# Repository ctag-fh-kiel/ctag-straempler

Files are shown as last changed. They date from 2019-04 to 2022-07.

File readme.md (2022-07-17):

# **CTAG Strämpler**
This repository contains the firmware and the hardwaredesigns (CTAG and [Antumbra](http://www.antumbra.eu/)) of Strämpler.

!!**NEW**!! Strämpler firmware can now be built in the cloud using Github actions
!!**NEW**!! Strämpler can now run [CTAG TBD](https://github.com/ctag-fh-kiel/ctag-tbd) as alternative firmware! Enclosed in /bin folder!

Strämpler harware UI

## What it is:
- Half streamer, half sampler, therefore called Strämpler (close to German word of Strampler meaning romper suit).
- Allows streaming of large audio files from SD card (limit 2GB file size due to FAT32 used).
- A eurorack modular synth module with 22 HP width and an internet connection.
- A bridge to connect to [freesound.org](https://freesound.org), to play with samples within your modular synth setup.
- Allows tweaking of your sound just like you'd do with a sampler + *a modular synth*.
- Allows to parameter tweak and modulate sounds by control voltage (CV), employing a complex modulation matrix.

## Why it is:
- A group of audio enthusiasts enjoying coding and hardware making.
- The sexiness of sampling for sound design and synthesis.
- The (subjective) need to have more sampling modules in the eurorack modular synth domain.
- The (subjective) need to make eurorack more compatible with internet of things.
- Build a platform to learn, build and practise skills, and engage students.
- To allow anyone to understand technology by offering open access.
- To benchmark the capabilities of the WiFi/BLE enabled [Espressif ESP32](https://docs.espressif.com/projects/esp-idf/en/latest/#) platform and get a deep understanding of it.
- To squeeze and optimize code so that it can work on a small embedded system.
- Because we can.
- Because of some inspiration of the [Elektron Octatrack](https://www.elektron.se/products/octatrack-mkii/).

## Features: 
- 2 voice eurorack sample streaming module.
- Streaming of large sound files from SD-card (limited by FAT32 2GB).
- Internet connection to [freesound.org](https://freesound.org), allows to download files through freesound.org api onto SD-card of module.
- One ADSR per voice to control sample amplitude.
- One band pass filter per voice with controllable base, width and Q. Can be used as low / high pass (biquad implmentation).
- Arbitrary playback speed adjustment (+/- 100%). 
- Pitching +/- 12 halftones, samples can be played e.g. using external gate / CV keyboard.
- Distortion per voice (tanh() saturation).
- Delay as send effect (stereo, ping pong, max delay time 1.5s).
- External stereo input, with delay send, mix with voices.
- Modulation matrix, where many parameters can be modulated using external CV.
- Gate and latch modes for sample playback.
- REST-API for user file upload (service discovery by MDNS / bonjour).
- 44.1kHz, 32 bit float internal resolution, 24 bit codec resolution, 12 bit CV input resolution sampled at 2KHz (yes, modulation in the audio range is possible to a certain extend), approx. 1ms DSP buffer latency  (32 words per channel).
- Approx. 100mA +12V / 10mA -12V power draw.

## Potential new features / current limitations / work to be done:
- Sampling of external input. 
- Upload to freesound.org.
- Improved sound browser, browse by tag, browse by search.
- More testing of modulation.
- More effects.
- More performance optimization.
- Automatic voice alternation.
- Bug identification and fixing.
- Code refactoring to make things more beautiful.
- More user friendly interaction.
- Documentation / tutorials.
- Your ideas?

## How to engage yourself:
- Join the [enthusiastic developer](https://codewithoutrules.com/2018/11/12/enthusiasts-vs-pragmatists/) team on Github.
- Help build and spread the hardware module (and the word).
- Use Strämpler to create cool sounds and music and share them (with a link to us).
- More ideas?

## Words of caution: 
- CTAG Strämpler does contain bugs, it comes without warranty of any kind, none of the authors are liable to damages arising by the use of it.
- CTAG Strämpler is an intermediate to advanced project, both in terms of hardware and software design:
    - In order to build the hardware you need intermediate to advanced SMD soldering skills and respective tools. I.e. the PCB contains many 0604 SMD components as well as TSSOP packages and a QFN. However, with a bit of practise you will be able to DIY build your own module. Dare and be rewarded, tackle the frustration on the path, it's worth it. The idea of the platform is also to boost your soldering skills, it *CAN* all be done by hand.
    - The software is built using [Espressif IDF](https://esp-idf.readthedocs.io) using the C programming language. Intermediate knowledge of C is required to understand the code. Furthermore, some basic DSP algorithms are applied. A DSP newbie, however, could take the project to really get rolling and build up on DSP capabilities. CTAG Strämpler is ideal to try out and play with your own DSP algorithms.
- The [Espressif ESP32](https://en.wikipedia.org/wiki/ESP32) platform used for CTAG Strämpler is, with regard to its computational power and I/O capabilities, hard at its limit. We're squeezing the platform here and are already surprised, what one can get out of $5 chip in the year 2019. Surely, other DSPs / microcontrollers could do a better job, but do they allow for internet of things as easily?

## How to get started / user manual:
See the [Wiki pages](https://github.com/ctag-fh-kiel/ctag-straempler/wiki) of this project.

## Build instructions
The easiest way is to create a fork on Github from this repository. Then make sure GitHub Actions are activated for your fork by going to the corresponding tab at your fork and clicking on the green button.
Every time you push new commits into your fork (master or dev branch) the action will build a new draft release, which will upon successful run of the action be available at your fork's release tab.

If you want to build on your own system, you can use a virtual development environment image with Docker (see here for [ESP IDF Docker instructions](https://docs.espressif.com/projects/esp-idf/en/latest/esp32/api-guides/tools/idf-docker-image.html)). 
Here are some steps:
- Install [Docker](https://www.docker.com/)
- Install [Git](https://git-scm.com/)
- Open a command line shell
- Clone the Strämpler repository and submodules with ```git clone --recurse-submodules https://github.com/ctag-fh-kiel/ctag-straempler.git``` and change into it with ```cd ctag-straempler```
- Build the firmware with ```docker run --rm -v $PWD:/project -w /project rma31/idf:v4.1-strampler idf.py build```

You can edit the source files using any IDE / text editor you like.
## Flash instructions
- Either download the firmware from the Github release tab or use your own
- Install [ESP Tool](https://github.com/espressif/esptool)
- Adapt the [Firmware flash script](https://github.com/ctag-fh-kiel/ctag-straempler/blob/master/bin/flash.sh) to your system needs and flash the firmware

## Hardware
All hardware design can be found [https://github.com/ctag-fh-kiel/esp32-eurorack-audio](https://github.com/ctag-fh-kiel/esp32-eurorack-audio).

## Links
- [Demonstration videos on YouTube](https://youtu.be/zmj8tKPHV8g).

## Licenses:
- Hardware is licensed under [Creative Commons Attribution-NonCommercial-ShareAlike 4.0 International (CC BY-NC-SA 4.0)](https://creativecommons.org/licenses/by-nc-sa/4.0/).
- Software licenses, see [license](LICENSE) file.
- Freesound license: [Freesound.org API terms](https://freesound.org/docs/api/terms_of_use.html) and [here](https://freesound.org/help/tos_api/) as well as the [freesound website terms of use](https://freesound.org/help/tos_web/).
- Don't forget to obey the license of the respective sound files used in your music. License details are shown for the individual sound file in your CTAG Strämpler sound browser, including the sound file authors name.

## Who made this happen:
- The team of [CTAG (Creative Technologies Arbeitsgruppe) at Kiel University of Applied Science](https://www.creative-technologies.de), including:
    - Robert Manzke
    - Phillip Lamp
    - Niklas Wantrupp
    - With kind support for the front panel design by David Knop from [instruments of things](http://www.instrumentsofthings.com/).
- [Antumbra](http://www.antumbra.eu/)
- More people like you :)

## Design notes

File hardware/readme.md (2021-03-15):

# Hardware
This directory contains two alternative hardware designs, the original CTAG and a beautiful smaller form factor redesign by [Antumbra](http://www.antumbra.eu/).
Apply a "git submodule update --init --recursive".

## CTAG 
Designs are in KiCad Format. Original hardware repo added through git submodule.

## Antumbra
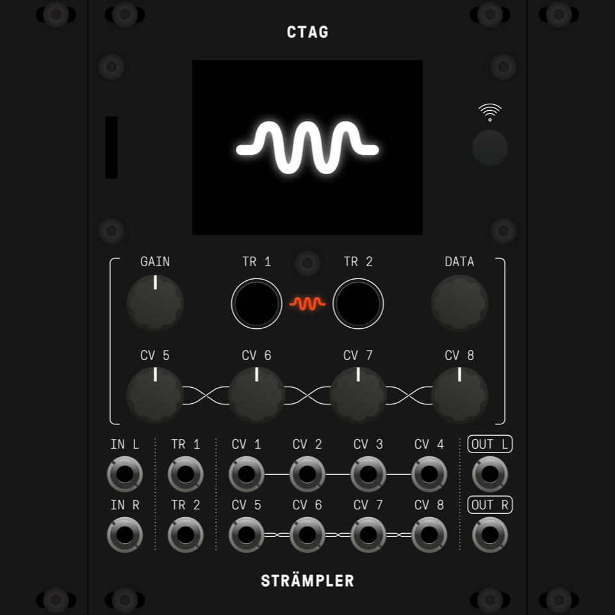
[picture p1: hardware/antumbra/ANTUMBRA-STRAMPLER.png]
Antumbra UI

Designs are in Eagle Cad Format.

[BOM](https://docs.google.com/spreadsheets/d/16I0Fnxrp7fq1aB0nhNF5OuEwzjhC1HZl9R4_WuAPDM4)

[Mouser cart](https://www.mouser.com/ProjectManager/ProjectDetail.aspx?AccessID=9c1a090daf)

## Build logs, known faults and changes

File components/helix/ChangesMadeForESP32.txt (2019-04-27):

The following changes have been made to the Helix MP3 decoder source code
for porting on to the ESP32 microcontroller. 

- Modified CNZ to use GCC default
- Modified MULSHIFT32 to not use assembler code

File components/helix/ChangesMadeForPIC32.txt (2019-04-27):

The following changes have been made to the Helix MP3 decoder source code
for porting on to the PIC32MX microcontroller. 

1. Commented out the assembly implementation of FASTABS() function in
assembly.h and replaced with the C equivalent.

2. Commented out the line 47 in file mp3dec.h as this may not be 
applicable to the PIC32.

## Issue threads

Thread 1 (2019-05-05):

Sample start, loop start/stop positions need update when sound changed

ctag-fh-kiel, 2019-05-05:
Sample start, loop start/stop positions seem to remain calculated for the previous sample, if new sample is loaded. They are set correctly once one edits the value in the playmodes menu.
Needs fix that values are set correctly upon new sound to slot assignment.

Closed 2019-05-06.

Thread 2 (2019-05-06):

Unable to build

morganrallen, 2019-05-06:
Hi all! I'm currently working on a ESP32 based synth project and looking for inspiration as this is quite foreign territory for me. While I'm comfortable with `ESP-IDF`, I feel like something might be missing.

I've ensure I have the latest xtensa tools, IDF is up to date (including submodules, python) but am met with this compilation error.

```
/home/morgan/devel/ctag-straempler/components/audio/audio.c:76:32: error: missing braces around initializer [-Werror=missing-braces]
 atomic_bool trigModeLatch[2] = {false, false};
                                ^
/home/morgan/devel/ctag-straempler/components/audio/audio.c:76:32: note: (near initialization for 'trigModeLatch')
/home/morgan/devel/ctag-straempler/components/audio/audio.c: In function 'enableTrigModeLatch':
/home/morgan/devel/ctag-straempler/components/audio/audio.c:945:24: error: incompatible types when assigning to type 'atomic_bool {aka struct <anonymous>}' from type 'int'
     trigModeLatch[vid] = true;
                        ^
/home/morgan/devel/ctag-straempler/components/audio/audio.c: In function 'disableTrigModeLatch':
/home/morgan/devel/ctag-straempler/components/audio/audio.c:949:24: error: incompatible types when assigning to type 'atomic_bool {aka struct <anonymous>}' from type 'int'
     trigModeLatch[vid] = false;
                        ^
/home/morgan/devel/ctag-straempler/components/audio/audio.c: In function 'audio_task':
/home/morgan/devel/ctag-straempler/components/audio/audio.c:1033:20: error: used struct type value where scalar is required
                 if(trigModeLatch[vid]){
                    ^
/home/morgan/devel/ctag-straempler/components/audio/audio.c: In function 'assignAudioFiles':
/home/morgan/devel/ctag-straempler/components/audio/audio.c:1179:43: error: 'FIL {aka struct <anonymous>}' has no member named 'cltbl'
                         audio_files[i].fil.cltbl = audio_files[i].clmt;
                                           ^
/home/morgan/devel/ctag-straempler/components/audio/audio.c:1180:43: error: 'FIL {aka struct <anonymous>}' has no member named 'cltbl'
                         audio_files[i].fil.cltbl[0] = SZ_TBL;
                                           ^
/home/morgan/devel/ctag-straempler/components/audio/audio.c: At top level:
cc1: warning: unrecognized command line option '-Wno-int-in-bool-context'
cc1: warning: unrecognized command line option '-Wno-memset-elt-size'
cc1: warning: unrecognized command line option '-Wno-format-truncation'
cc1: warning: unrecognized command line option '-Wno-switch-unreachable'
cc1: warning: unrecognized command line option '-Wno-unused-const-variable'
cc1: warning: unrecognized command line option '-Wno-implicit-fallthrough'
cc1: warning: unrecognized command line option '-Wno-cast-function-type'
cc1: warning: unrecognized command line option '-Wno-misleading-indentation'
cc1: warning: unrecognized command line option '-Wno-stringop-truncation'
cc1: warning: unrecognized command line option '-Wno-format-overflow'
cc1: warning: unrecognized command line option '-Wno-frame-address'
```

Trying to hack through these just leads to more and one warning of note...
```
/home/morgan/devel/ESP32/esp-idf/components/esp32/include/rom/lldesc.h:1:2: warning: #warning rom/lldesc.h is deprecated, please use esp32/rom/lldesc.h instead [-Wcpp]
```

This makes me think you're possibly using an old checkout of IDF?

ctag-fh-kiel, 2019-05-06:
Hi morganrallen,

In order to build the project, you need the newest compiler GCC 8.2, see this post https://esp32.com/viewtopic.php?t=7400

Also, we use a modified ESP-IDF due to issues with the fatfs implementation.

Please check out the wiki here as well, on how to build the project:
https://github.com/ctag-fh-kiel/ctag-straempler/wiki/GettingStarted

Do let us know if you still have problems ;)

ctag-fh-kiel, 2019-05-07:
Closing this issue...

morganrallen, 2019-05-07:
Ah crap! I overlooked the wiki. I will give that a try when I've got free time again. Maybe call out build instruction on the readme?

ctag-fh-kiel, 2019-05-08:
Updated the readme, thanks for the advice...

Closed 2019-05-07.

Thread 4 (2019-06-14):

Playback partially corrupted when start + PBspeed modulated

ctag-fh-kiel, 2019-06-14:
Seems as if playback goes beyond sample limit, resulting in noise and partially crashes...
Seems to happen only in single shot mode.

ctag-fh-kiel, 2019-06-14:
Appears fixed in d439aac...

Closed 2019-06-14.

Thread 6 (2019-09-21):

Setting up toolchain as per instructions - failed ! (My fault but struggling)

forestcaver, 2019-09-21:
I’m really struggling to build the firmware.
I’ve followed the instructions to the letter
I have unpacked the binary download of gcc 8.2

I am really unsure whether and how to replace the xtensa / esp-idf toolchain
I’ve tried changing my path to the gcc 8.2 and setting the prefix in the menuconfig
But I’m really struggling to setup the paths to gcc 8.2
I cant find anything useful on the esp forums.

I appreciate it’s not really an issue with the code but dont know how else to ask for help !

ctag-fh-kiel, 2019-09-23:
Hi there, thanks for your request.

Please check the esp32.com forum for the post regarding the GCC 8.2 toolchain:
[https://www.esp32.com/viewtopic.php?t=7400](https://www.esp32.com/viewtopic.php?t=7400)

We have been using esp32-2019r1-rc2 (second post).

I recommend erasing (or moving) the old xtensa-gcc and extracting the toolchain to "~/xtensa-esp32-elf". Additionally, you also need the ULP toolchain.

Make sure your "PATH" environment includes "~/xtensa-esp32-elf/bin" so that the tools are found.

Hope this helps, let us know if you have further issues.

forestcaver, 2019-09-24:
Thanks for the reply.

I had followed that (second) forum post and been using the pre-compiled binary.
(arm-none-eabi-)

I have been using the ULP toolchain.
My PATH was correct.

I tried deleting the old xtensa-gcc
I’m still seeing compile-time errors.
I tried setting up sdkconfig to have the arm-none-eabi- prefix.

Thoughts - should I compile gcc and the toolchain from scratch?

I’m sort of at a loss !!
Ive tried setting it all up from scratch several times with the same result.

Really sorry to bug you...

ctag-fh-kiel, 2019-09-24:
When you configure the project (make menuconfig) did you enable "Disable new warnings introduced in GCC 6 - 8" ? Also, did you configure for release mode?

It is not necessary to compile the whole toolchain from source, we have never done it.

ctag-fh-kiel, 2019-09-24:
This is in the compiler options sub menu...

forestcaver, 2019-10-17:
Sorry - didnt see your other comments! Only got a notification when it was closed!

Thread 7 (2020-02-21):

firmware crashes when trying to edit effects or cv matrix.

thopman, 2020-02-21:
firmware crashes when trying to edit effects or cv matrix. pretty much says it all. Firmware is the ready built version in the bin folder. When crashed the screen will freeze and all functionality stops.

ctag-fh-kiel, 2020-02-21:
Thanks for reporting the issue, can you be a bit more specific, does it always crash on your system, immediately when you try to edit efx and / or cv matrix? (on my systems it works stable). What freesound sample are you manipulating? Or is it your own one?

thopman, 2020-02-21:
i have no sample loaded. all i do is power up the module and play around in the effects section. As soon as i try to edit a parameter the screen freezes and becomes fully unresponsive. I have 2 modules, one working fine but was flashed via the vagrant esp-idf environment and compiled from the latest source and one flashed with the ./flash command in the bin folder. i have since deleted that vm so i used the compiled firmware.

ctag-fh-kiel, 2020-02-22:
That's strange, I will test myself, the binary should be fine...

kooops, 2020-02-23:
I have a similar issue: firmware will crashes whenever I enter a third level of the menu (for example trying to edit the type of gate). If I let the ctag runing without touching anything it'll be fine. However trying to read a sample either from the gate input or the switch will not launch anything. Trying to compile under the vagrant machine will return an error on the audio main.

ctag-fh-kiel, 2020-02-23:
Ok, I will test the latest firmware asap... @kooops not beeing able to trigger sound like a cold solder point on the button?

ctag-fh-kiel, 2020-02-23:
Ah, would it be possible for you to connect to the module with USB using the micro USB plug and get the monitor output? --> make monitor or idf.py monitor
The output give some hints on the error...

kooops, 2020-02-24:
I don't think It's a cold solder joint as I checked and this is just an example of its behaviour. In other word it will freeze consistently whenever I enter a subMenu. Here is the log from my terminal following a make (sorry if its a long paste )
 App "smplr" version: v0.8-22-g8414af8-dirty
CC build/audio/audio.o
/home/vagrant/ctag-straempler/components/audio/audio.c:76:31: error: missing braces around initializer [-Werror=missing-braces]
 atomic_bool trigModeLatch[2] ={false, false};
                               ^
/home/vagrant/ctag-straempler/components/audio/audio.c: In function 'enableTrigModeLatch':
/home/vagrant/ctag-straempler/components/audio/audio.c:946:24: error: incompatible types when assigning to type 'atomic_bool' {aka 'struct <anonymous>'} from type 'int'
     trigModeLatch[vid] = true;
                        ^
/home/vagrant/ctag-straempler/components/audio/audio.c: In function 'disableTrigModeLatch':
/home/vagrant/ctag-straempler/components/audio/audio.c:951:24: error: incompatible types when assigning to type 'atomic_bool' {aka 'struct <anonymous>'} from type 'int'
     trigModeLatch[vid] = false;
                        ^
/home/vagrant/ctag-straempler/components/audio/audio.c: In function 'audio_task':
/home/vagrant/ctag-straempler/components/audio/audio.c:1035:20: error: used struct type value where scalar is required
                 if(trigModeLatch[vid]){
                    ^~~~~~~~~~~~~
cc1: some warnings being treated as errors
/home/vagrant/esp-idf/make/component_wrapper.mk:289: recipe for target 'audio.o' failed
make[1]: *** [audio.o] Error 1
/home/vagrant/esp-idf/make/project.mk:582: recipe for target 'component-audio-build' failed
make: *** [component-audio-build] Error 2
any idea?

ctag-fh-kiel, 2020-02-24:
This is the terminal output, when you are trying to compile the application. It seems you are not using gcc 8.2, see here https://github.com/ctag-fh-kiel/ctag-straempler/wiki/GettingStarted#setup-toolchain and here https://esp32.com/viewtopic.php?t=7400
What I meant is the the monitor output when you attach the module through the USB cable and then do "make monitor", that should connect with the module and then give real-time information, about the crash during run-time...

kooops, 2020-02-24:
here is the output of a make simple monitor
 make simple_monitorToolchain path: /home/vagrant/xtensa-esp32-elf/bin/xtensa-esp32-elf-gcc
WARNING: Toolchain version is not supported: esp32-2019r1-rc2
Expected to see version: crosstool-ng-1.22.0-80-g6c4433a
Please check ESP-IDF setup instructions and update the toolchain, or proceed at your own risk.
WARNING: Compiler version is not supported: 8.2.0
Expected to see version(s): 5.2.0
Please check ESP-IDF setup instructions and update the toolchain, or proceed at your own risk.
Python requirements from /home/vagrant/esp-idf/requirements.txt are satisfied.
--- forcing DTR inactive
--- forcing RTS inactive
--- Miniterm on /dev/ttyUSB0  115200,8,N,1 ---
--- Quit: Ctrl+] | Menu: Ctrl+T | Help: Ctrl+T followed by Ctrl+H ---
ets Jun  8 2016 00:22:57

rst:0x1 (POWERON_RESET),boot:0x1b (SPI_FAST_FLASH_BOOT)
configsip: 0, SPIWP:0xee
clk_drv:0x00,q_drv:0x00,d_drv:0x00,cs0_drv:0x00,hd_drv:0x00,wp_drv:0x00
mode:DIO, clock div:1
load:0x3fff0018,len:4
load:0x3fff001c,len:6436
load:0x40078000,len:10456
load:0x40080400,len:7068
entry 0x40080750
I (29) boot: ESP-IDF v4.0-dev-487-g784daf8 2nd stage bootloader
I (29) boot: compile time 17:47:26
I (29) boot: Enabling RNG early entropy source...
I (35) qio_mode: Enabling default flash chip QIO
I (40) boot: SPI Speed      : 80MHz
I (44) boot: SPI Mode       : QIO
I (48) boot: SPI Flash Size : 16MB
I (52) boot: Partition Table:
I (56) boot: ## Label            Usage          Type ST Offset   Length
I (63) boot:  0 nvs              WiFi data        01 02 00009000 00006000
I (71) boot:  1 phy_init         RF data          01 01 0000f000 00001000
I (78) boot:  2 factory          factory app      00 00 00010000 00200000
I (86) boot: End of partition table
I (90) esp_image: segment 0: paddr=0x00010020 vaddr=0x3f400020 size=0x29b90 (170896) map
I (145) esp_image: segment 1: paddr=0x00039bb8 vaddr=0x3ffb0000 size=0x06114 ( 24852) load
I (152) esp_image: segment 2: paddr=0x0003fcd4 vaddr=0x40080000 size=0x0033c (   828) load
I (153) esp_image: segment 3: paddr=0x00040018 vaddr=0x400d0018 size=0xbf104 (782596) map
I (371) esp_image: segment 4: paddr=0x000ff124 vaddr=0x4008033c size=0x000c4 (   196) load
I (372) esp_image: segment 5: paddr=0x000ff1f0 vaddr=0x40080400 size=0x16a34 ( 92724) load
I (423) boot: Loaded app from partition at offset 0x10000
I (423) boot: Disabling RNG early entropy source...
I (424) spiram: Found 64MBit SPI RAM device
I (428) spiram: SPI RAM mode: flash 80m sram 80m
I (434) spiram: PSRAM initialized, cache is in low/high (2-core) mode.
I (441) cpu_start: Pro cpu up.
I (445) cpu_start: Application information:
I (450) cpu_start: Project name:     smplr
I (454) cpu_start: App version:      v0.8-21-gd54f802-dirty
I (461) cpu_start: Compile time:     Jul 21 2019 17:47:37
I (467) cpu_start: ELF file SHA256:  4a55c6babb07d1bd...
I (473) cpu_start: ESP-IDF:          v4.0-dev-487-g784daf8
I (479) cpu_start: Starting app cpu, entry point is 0x400814f4
I (0) cpu_start: App cpu up.
I (964) spiram: SPI SRAM memory test OK
I (964) heap_init: Initializing. RAM available for dynamic allocation:
I (964) heap_init: At 3FFAE6E0 len 00001920 (6 KiB): DRAM
I (970) heap_init: At 3FFC0B20 len 0001F4E0 (125 KiB): DRAM
I (976) heap_init: At 3FFE0440 len 00003AE0 (14 KiB): D/IRAM
I (983) heap_init: At 3FFE4350 len 0001BCB0 (111 KiB): D/IRAM
I (989) heap_init: At 40096E34 len 000091CC (36 KiB): IRAM
I (995) cpu_start: Pro cpu start user code
I (1000) spiram: Adding pool of 4096K of external SPI memory to heap allocator
I (125) cpu_start: Starting scheduler on PRO CPU.
I (0) cpu_start: Starting scheduler on APP CPU.
I (126) SD: Initializing SD card
I (126) gpio: GPIO[13]| InputEn: 0| OutputEn: 1| OpenDrain: 0| Pullup: 0| Pulldown: 0| Intr:0
Name: SMI
Type: SDHC/SDXC
Speed: 40 MHz
Size: 7680MB
SPI: display device added to spi bus (1)
SPI: attached display device, speed=8000000
SPI: bus uses native pins: false
SPI: display init...
OK
SPI: Max rd speed = 8000000
SPI: Changed speed to 26666666
I (5136) gpio: GPIO[33]| InputEn: 1| OutputEn: 0| OpenDrain: 0| Pullup: 0| Pulldown: 0| Intr:2
I (5136) gpio: GPIO[34]| InputEn: 1| OutputEn: 0| OpenDrain: 0| Pullup: 0| Pulldown: 0| Intr:2
I (5136) gpio: GPIO[35]| InputEn: 1| OutputEn: 0| OpenDrain: 0| Pullup: 0| Pulldown: 0| Intr:2
I (5146) gpio: GPIO[36]| InputEn: 1| OutputEn: 0| OpenDrain: 0| Pullup: 0| Pulldown: 0| Intr:0
I (5156) gpio: GPIO[39]| InputEn: 1| OutputEn: 0| OpenDrain: 0| Pullup: 0| Pulldown: 0| Intr:0
I (5166) AUDIO: Starting audio task
I (5176) I2S: DMA Malloc info, datalen=blocksize=256, dma_buf_count=4
I (5176) I2S: DMA Malloc info, datalen=blocksize=256, dma_buf_count=4
I (5186) I2S: APLL: Req RATE: 44100, real rate: 43945.238, BITS: 32, CLKM: 1, BCK_M: 8, MCLK: 22499962.000, SCLK: 2812495.250000, diva: 1, divb: 0
I (5396) wifi: wifi driver task: 3ffe1948, prio:23, stack:3584, core=0
I (5396) wifi: wifi firmware version: 7c00966
I (5396) wifi: config NVS flash: enabled
I (5396) wifi: config nano formating: disabled
I (5406) system_api: Base MAC address is not set, read default base MAC address from BLK0 of EFUSE
I (5416) system_api: Base MAC address is not set, read default base MAC address from BLK0 of EFUSE
I (5446) wifi: Init dynamic tx buffer num: 32
I (5446) wifi: Init data frame dynamic rx buffer num: 32
I (5446) wifi: Init management frame dynamic rx buffer num: 32
I (5446) wifi: Init management short buffer num: 32
I (5446) wifi: Init static rx buffer size: 1600
I (5456) wifi: Init static rx buffer num: 10
I (5456) wifi: Init dynamic rx buffer num: 32
I (5466) WIFI: Setting WiFi configuration SSID rajufree
I (5546) phy: phy_version: 4100, 2a5dd04, Jan 23 2019, 21:00:07, 0, 0
I (5546) wifi: mode : sta (24:0a:c4:bf:f7:bc)
I (6146) wifi: new:<6,0>, old:<1,0>, ap:<255,255>, sta:<6,0>, prof:1
I (6816) wifi: state: init -> auth (b0)
I (6826) wifi: state: auth -> assoc (0)
I (6826) wifi: state: assoc -> run (10)

I (6836) wifi: pm start, type: 1

I (9896) tcpip_adapter: sta ip: 192.168.0.23, mask: 255.255.255.0, gw: 192.168.0.254
I (9896) WIFI: Initializing SNTP
I (9896) WIFI: Waiting for system time to be set... (1/20)
I (10396) WIFI: System time is set.
I (10396) MDNS: Initialize service...
I (10396) REST-API: Starting server on port: '80', prio 5
I (10396) REST-API: Registering URI handlers
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
kooops, 2020-02-24:
here is the content of my sd card
[SDcrash.zip](https://github.com/ctag-fh-kiel/ctag-straempler/files/4244249/SDcrash.zip)
Just like Thopman : same behaviour with a 40m freq it still freeze.

ctag-fh-kiel, 2020-02-24:
Ok, I have commited a new branch for 40MHz settings https://github.com/ctag-fh-kiel/ctag-straempler/tree/40MHz

Please check this...

ctag-fh-kiel, 2020-02-24:
I tried your SD card data, again no problems on my end, everything works as it should.
Very strange, maybe some cold solder points? Maybe PSU voltage issues?
Sorry I can't reproduce it :( I have erased you SDCARD post, as it contains secrets...

thopman, 2020-02-24:
i tried the 40Mhz branch and the problem still persists. I had to change the ./flash.sh script and the sdkconfig file to use /dev/ttyUSB0 but apart from that i changed nothing. the Wrover modules i have are these:  356-ESP32WROIB(16MB) (mouser part number),
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

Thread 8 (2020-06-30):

Where to buy it ?

0mars, 2020-06-30:
everylink on modulargrid is dead, the project is open source, but are there any builds available or kits ?

lechmaof, 2020-07-01:
I ordered the panels and pcbs from JLCpcb, 5 sets for about 45 euros total, incl shipping (czech republic), tax etc. Still haven't ordered the parts to actually build it though.

0mars, 2020-07-01:
@lechmaof very interesting project. I want a full kit or fully assembled if possible.

0mars, 2020-07-01:
keep me posted!

ctag-fh-kiel, 2020-07-01:
We don't sell kits or assembled modules, however, there may be some builders out there who could do it for you. All design files are open source cc-sa-by-nc license (non-commercial where we are totally fine if someone builds a few of them and sells them, just not on a larger e.g. >10).

0mars, 2020-07-01:
can u sell at least pcb and panel ?

Best,
Omar

On Wed, Jul 1, 2020 at 12:45 PM Robert Manzke <notifications@github.com>
wrote:

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

ctag-fh-kiel, 2020-07-01:
Hi Omar, it's easy to order e.g. from jlcpcb.com, just drag and drop these files in the quotation menu:
https://github.com/ctag-fh-kiel/esp32-eurorack-audio/blob/rev-d/Gerber/Gerber.rar (PCB, 4-layers)
https://github.com/ctag-fh-kiel/esp32-eurorack-audio/blob/rev-d/GerberFrontplate/GerberFrontplate.rar (Front Plate, choose your own color)

For building it, here is the bill of materials (BOM):
https://github.com/ctag-fh-kiel/esp32-eurorack-audio/blob/rev-d/ESP32-Eurorack-Audio-BOM-RevD.xlsx

Let me know if you have problems...

0mars, 2020-07-01:
ok thanks

Closed 2021-02-07.

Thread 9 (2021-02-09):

esp-adf

colesnicov, 2021-02-09:
Hello.  why don't you use [ESP-ADF](https://github.com/espressif/esp-adf)?

ctag-fh-kiel, 2021-02-10:
Strämpler was conceived before ADF was published...
For the use-case of Strämpler, I am unsure what benefits ADF would have, are there any?

milkowski, 2021-03-18:
For current ESP32 core probably not much (although it has much broader audio format support), but if we were considering upgrade to ESP32-S2/S3 modules with Xtensa X7 cores, that have additional DSP-oriented instructions it would be very beneficial. Also since I see there have been new activity in this project recently, with new hardware design and TBD firmware option, I think it would be great to try to unify Straempler and TBD functionality in new Straempler 2/NX/+/wathever, using those new chips and updated hardware (with buttons and separate gain controls per input channel to create functional superset for cases where TBD controls will be not enough).
I would interested in helping to achieve this goal, since currently I'm in the process of assembling few Straempler and TBD modules for myself.

ctag-fh-kiel, 2021-03-19:
Absolutely, it would be great to unify both platforms and create better versions. I plan hardware iterations towards autumn/winter this year, as summer is reserved for other things already :)
It would be great to have you onboard! Thanks for the interest and let me know how happy you are with the modules... Cheers:)

Closed 2021-09-02.

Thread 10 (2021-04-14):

Wifi boot

antumbramodular, 2021-04-14:
Issue when available extra power is low and WIFI is not recognised: the module keeps restarting. Entering the wifi data via editing the config file on the SD card solved the issue. Possible solution would be disabling wifi on boot by pressing some combination of buttons, and re-enabling it when a new wifi password is entered. It would be nice if the module could store more wifi passwords at once.

bretdennison, 2022-05-15:
Figured I would share an issue i ran into that appears to be related to wifi.  If I power up the module with the antenna screwed in, the module appears to continuously reboot over and over.  If I unscrew the antenna, and then power it up, it boots up fine.  Then, if I want to use the wifi, I screw in the antenna and it works most of the time.  Not sure of the cause of this. Hopefully this helps someone else.

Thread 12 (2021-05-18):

SD Card Config Files ?

bretdennison, 2021-05-18:
I flashed the ESP32 using the pre-built binaries.  It would appear I still need the config file(s) for the SD card?  I am unsure where to find this.

ctag-fh-kiel, 2021-06-25:
Yeah, the ESP32 is picky with the type of SD cards, some are accepted some are not, some are accepted by read too slow for sample playback.
I have been using SanDisk 4GB cards quite successfully.

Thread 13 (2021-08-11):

Antumbra hardware has misalligned LCD hole position on the panel PCB

milkowski, 2021-08-11:
The Antumbra version of hardware has wrong size and placing of the LCD hole on the front panel which covers part of the GUI on the screen. Photo attached.
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

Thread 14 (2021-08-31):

Unable to flash

guytaylor, 2021-08-31:
Hi there,
I am having an issue trying to flash my strampler.
From what I have read online, it would appear to be a hardware issue. Do you think this could be the case from the logs?
Thanks

This is the chip I am using, which seems to have the Flash onboard: https://au.mouser.com/ProductDetail/356-ESP32-WROVER-IB

This is what the esptool.py output looks like, followed by a fuse summary:

PS M:\_uBoms_\Strampler\ctag-straempler-master\bin> esptool.py --chip esp32 --port COM9 --before default_reset --after hard_reset write_flash -z --flash_mode dio --flash_freq 80m --flash_size detect 0x1000 bootloader.bin 0x10000 smplr.bin 0x8000 partitions.bin
esptool.py v3.1-dev
Serial port COM9
Connecting....
Chip is ESP32-D0WD (revision 1)
Features: WiFi, BT, Dual Core, 240MHz, VRef calibration in efuse, Coding Scheme None
Crystal is 40MHz
MAC: ac:67:b2:5b:ae:a4
Uploading stub...
Running stub...
Stub running...
Configuring flash size...
Warning: Could not auto-detect Flash size (FlashID=0x0, SizeID=0x0), defaulting to 4MB
Flash will be erased from 0x00001000 to 0x00006fff...
Flash will be erased from 0x00010000 to 0x00115fff...
Flash will be erased from 0x00008000 to 0x00008fff...
Flash params set to 0x022f
Compressed 24064 bytes to 14974...
Writing at 0x00001000... (100 %)
A fatal error occurred: Timed out waiting for packet header

PS M:\_uBoms_\Strampler\ctag-straempler-master\bin> espefuse.py --port COM9 summary
Connecting....
Detecting chip type... ESP32
espefuse.py v3.1-dev
EFUSE_NAME (Block)                       Description  = [Meaningful Value] [Readable/Writeable] (Hex Value)
----------------------------------------------------------------------------------------
Calibration fuses:
BLK3_PART_RESERVE (BLOCK0):              BLOCK3 partially served for ADC calibration data   = False R/W (0b0)
ADC_VREF (BLOCK0):                       Voltage reference calibration                      = 1149 R/W (0b00111)

Config fuses:
XPD_SDIO_FORCE (BLOCK0):                 Ignore MTDI pin (GPIO12) for VDD_SDIO on reset     = False R/W (0b0)
XPD_SDIO_REG (BLOCK0):                   If XPD_SDIO_FORCE, enable VDD_SDIO reg on reset    = False R/W (0b0)
XPD_SDIO_TIEH (BLOCK0):                  If XPD_SDIO_FORCE & XPD_SDIO_REG                   = 1.8V R/W (0b0)
CLK8M_FREQ (BLOCK0):                     8MHz clock freq override                           = 54 R/W (0x36)
SPI_PAD_CONFIG_CLK (BLOCK0):             Override SD_CLK pad (GPIO6/SPICLK)                 = 0 R/W (0b00000)
SPI_PAD_CONFIG_Q (BLOCK0):               Override SD_DATA_0 pad (GPIO7/SPIQ)                = 0 R/W (0b00000)
SPI_PAD_CONFIG_D (BLOCK0):               Override SD_DATA_1 pad (GPIO8/SPID)                = 0 R/W (0b00000)
SPI_PAD_CONFIG_HD (BLOCK0):              Override SD_DATA_2 pad (GPIO9/SPIHD)               = 0 R/W (0b00000)
SPI_PAD_CONFIG_CS0 (BLOCK0):             Override SD_CMD pad (GPIO11/SPICS0)                = 0 R/W (0b00000)
DISABLE_SDIO_HOST (BLOCK0):              Disable SDIO host                                  = False R/W (0b0)

Efuse fuses:
WR_DIS (BLOCK0):                         Efuse write disable mask                           = 0 R/W (0x0000)
RD_DIS (BLOCK0):                         Efuse read disable mask                            = 0 R/W (0x0)
CODING_SCHEME (BLOCK0):                  Efuse variable block length scheme
   = NONE (BLK1-3 len=256 bits) R/W (0b00)
KEY_STATUS (BLOCK0):                     Usage of efuse block 3 (reserved)                  = False R/W (0b0)

Identity fuses:
MAC (BLOCK0):                            Factory MAC Address
   = ac:67:b2:5b:ae:a4 (CRC 0xb1 OK) R/W
MAC_CRC (BLOCK0):                        CRC8 for factory MAC address                       = 177 R/W (0xb1)
CHIP_VER_REV1 (BLOCK0):                  Silicon Revision 1                                 = True R/W (0b1)
CHIP_VER_REV2 (BLOCK0):                  Silicon Revision 2                                 = False R/W (0b0)
CHIP_VERSION (BLOCK0):                   Reserved for future chip versions                  = 2 R/W (0b10)
CHIP_PACKAGE (BLOCK0):                   Chip package identifier                            = 1 R/W (0b001)
MAC_VERSION (BLOCK3):                    Version of the MAC field                           = 0 R/W (0x00)

Security fuses:
FLASH_CRYPT_CNT (BLOCK0):                Flash encryption mode counter                      = 0 R/W (0b0000000)
UART_DOWNLOAD_DIS (BLOCK0):              Disable UART download mode (ESP32 rev3 only)       = False R/W (0b0)
FLASH_CRYPT_CONFIG (BLOCK0):             Flash encryption config (key tweak bits)           = 0 R/W (0x0)
CONSOLE_DEBUG_DISABLE (BLOCK0):          Disable ROM BASIC interpreter fallback             = True R/W (0b1)
ABS_DONE_0 (BLOCK0):                     Secure boot V1 is enabled for bootloader image     = False R/W (0b0)
ABS_DONE_1 (BLOCK0):                     Secure boot V2 is enabled for bootloader image     = False R/W (0b0)
JTAG_DISABLE (BLOCK0):                   Disable JTAG                                       = False R/W (0b0)
DISABLE_DL_ENCRYPT (BLOCK0):             Disable flash encryption in UART bootloader        = False R/W (0b0)
DISABLE_DL_DECRYPT (BLOCK0):             Disable flash decryption in UART bootloader        = False R/W (0b0)
DISABLE_DL_CACHE (BLOCK0):               Disable flash cache in UART bootloader             = False R/W (0b0)
BLOCK1 (BLOCK1):                         Flash encryption key
   = 00 00 00 00 00 00 00 00 00 00 00 00 00 00 00 00 00 00 00 00 00 00 00 00 00 00 00 00 00 00 00 00 R/W
BLOCK2 (BLOCK2):                         Secure boot key
   = 00 00 00 00 00 00 00 00 00 00 00 00 00 00 00 00 00 00 00 00 00 00 00 00 00 00 00 00 00 00 00 00 R/W
BLOCK3 (BLOCK3):                         Variable Block 3
   = 00 00 00 00 00 00 00 00 00 00 00 00 00 00 00 00 00 00 00 00 00 00 00 00 00 00 00 00 00 00 00 00 R/W

Flash voltage (VDD_SDIO) determined by GPIO12 on reset (High for 1.8V, Low/NC for 3.3V).

ctag-fh-kiel, 2021-08-31:
This is a strange error message, I have never seen it. Probably a hardware
issue. Did you configure for 16MB flash size with menuconfig (this should
be done)?

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

guytaylor, 2021-08-31:
Hi there, thanks for the quick reply :)
No, all I did was attempt the command line above which I got from flash.sh in the bin folder.
I did not 'configure for 16MB flash size with menuconfig' and can't seem to find any info on how to do that. Could you please tell me how? I assume I have missed a step!
Thank you

ctag-fh-kiel, 2021-08-31:
If you just want to flash the stock firmware, executing flash.sh (with
adapted serial port to your system) should suffice.

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

guytaylor, 2021-08-31:
ok thanks. i will try replacing the esp32.

ctag-fh-kiel, 2021-08-31:
first check your soldering points, I'd say. You could try to pre-flash your
ESP module using a hardware adaptor prior to soldering it on the Strämpler
PCB. They are available at Ebay, Aliexpress etc.

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

guytaylor, 2021-08-31:
I pulled off the esp32 and reflowed it, and now it is working. thanks for you help

Closed 2021-08-31.

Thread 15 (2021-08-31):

Never ending reboot loop

guytaylor, 2021-08-31:
Hello again,
I am using the firmware in the bin folder
So I got it up and running and it was working fine.
Then I went to settings, entered my wifi credentials and freesound token.
Then I went to slot, and tried to end a freesound id.
That's when the reboot cycle started.

So I removed, the SD and checked the details in it. there are correct.
I tried repowering it with and without SD, it keeps rebooting.
So I finally tried to reflash it, powered it up without SD, and it keeps rebooting.

Not sure quite what to do now.
Any help appreciated.

ctag-fh-kiel, 2021-08-31:
I'd guess it is an SD card issue. Try another card, check the soldering
points and contact points of the sd card connector. Reformat the SD card.
Boot with empty SD card, then edit the files again on the PC, then reboot
on Strämpler. You can also debug what is happening by having the serial
cable connected and use a monitor. The esp outputs debug info (make monitor
or idf.py monitor).

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

guytaylor, 2021-08-31:
Hi,
I've checked and reflowed the SD card holder.
No luck with multiple different SD cards (I tried about 5 of different sizes - reformatted to FAT32).
When I put in a new card, it initialised it, and I can see all the files, on the SD card, but then it went into the endless loop
Setting the network details made no difference, back to loop

Would you expect it to reboot in a loop, even with no SD card in the unit? This is making me think it's not the SD?

I am not having much luck getting idf.py monitor working...
I initially assumed it was just an exe I could run, but is it correct that it is an alternative build that has the monitoring built-in?  Do I need to build the full source to get that up and running?
thanks again

ctag-fh-kiel, 2021-08-31:
a simple monitor like putty should work, just select the correct baud rate
(should be 115200).

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

guytaylor, 2021-08-31:
Hi, putty worked, thanks.

Here is the log when I had an SD card in with my network credentials set:
Note: just before the reboot the line after where my SSID is specified, there is a corruption in the string:
"I (1976) WIFI: Setting WiFi configuration SSID SPACE
I (2076) phy: phy_v▒ets Jun  8 2016 00:22:57"

I have setup DHCP on my router for the MAC address that was in the build. But I never see any attempt to connect in my router logs. The device is near my wifi router. Does it support DHCP?

It would appear that on attempting to set the WIFI details, it reboots without any indication of why in the logs.
Any idea what I could try next?

*** full log cycle (after this I included the log for when there was no SD card inserted)

from BLK0 of EFUSE
I (1956) wifi: Init dynamic tx buffer num: 32
I (1956) wifi: Init data frame dynamic rx buffer num: 32
I (1956) wifi: Init management frame dynamic rx buffer num: 32
I (1956) wifi: Init management short buffer num: 32
I (1966) wifi: Init static rx buffer size: 1600
I (1966) wifi: Init static rx buffer num: 10
I (1966) wifi: Init dynamic rx buffer num: 32
I (1976) WIFI: Setting WiFi configuration SSID SPACE
I (2076) phy: phy_v▒ets Jun  8 2016 00:22:57

rst:0x1 (POWERON_RESET),boot:0x1b (SPI_FAST_FLASH_BOOT)
configsip: 0, SPIWP:0xee
clk_drv:0x00,q_drv:0x00,d_drv:0x00,cs0_drv:0x00,hd_drv:0x00,wp_drv:0x00
mode:DIO, clock div:1
load:0x3fff0018,len:4
load:0x3fff001c,len:6436
load:0x40078000,len:10456
load:0x40080400,len:7068
entry 0x40080750
I (29) boot: ESP-IDF v4.0-dev-487-g784daf8 2nd stage bootloader
I (29) boot: compile time 17:47:26
I (29) boot: Enabling RNG early entropy source...
I (35) qio_mode: Enabling default flash chip QIO
I (40) boot: SPI Speed      : 80MHz
I (44) boot: SPI Mode       : QIO
I (48) boot: SPI Flash Size : 4MB
I (52) boot: Partition Table:
I (56) boot: ## Label            Usage          Type ST Offset   Length
I (63) boot:  0 nvs              WiFi data        01 02 00009000 00006000
I (70) boot:  1 phy_init         RF data          01 01 0000f000 00001000
I (78) boot:  2 factory          factory app      00 00 00010000 00200000
I (85) boot: End of partition table
I (90) esp_image: segment 0: paddr=0x00010020 vaddr=0x3f400020 size=0x29b90 (170896) map
I (145) esp_image: segment 1: paddr=0x00039bb8 vaddr=0x3ffb0000 size=0x06114 ( 24852) load
I (152) esp_image: segment 2: paddr=0x0003fcd4 vaddr=0x40080000 size=0x0033c (   828) load
I (153) esp_image: segment 3: paddr=0x00040018 vaddr=0x400d0018 size=0xbf104 (782596) map
I (371) esp_image: segment 4: paddr=0x000ff124 vaddr=0x4008033c size=0x000c4 (   196) load
I (371) esp_image: segment 5: paddr=0x000ff1f0 vaddr=0x40080400 size=0x16a34 ( 92724) load
I (423) boot: Loaded app from partition at offset 0x10000
I (423) boot: Disabling RNG early entropy source...
I (424) spiram: Found 64MBit SPI RAM device
I (428) spiram: SPI RAM mode: flash 80m sram 80m
I (433) spiram: PSRAM initialized, cache is in low/high (2-core) mode.
I (441) cpu_start: Pro cpu up.
I (444) cpu_start: Application information:
I (449) cpu_start: Project name:     smplr
I (454) cpu_start: App version:      v0.8-21-gd54f802-dirty
I (460) cpu_start: Compile time:     Jul 21 2019 17:47:37
I (466) cpu_start: ELF file SHA256:  4a55c6babb07d1bd...
I (472) cpu_start: ESP-IDF:          v4.0-dev-487-g784daf8
I (479) cpu_start: Starting app cpu, entry point is 0x400814f4
I (0) cpu_start: App cpu up.
I (963) spiram: SPI SRAM memory test OK
I (964) heap_init: Initializing. RAM available for dynamic allocation:
I (964) heap_init: At 3FFAE6E0 len 00001920 (6 KiB): DRAM
I (970) heap_init: At 3FFC0B20 len 0001F4E0 (125 KiB): DRAM
I (976) heap_init: At 3FFE0440 len 00003AE0 (14 KiB): D/IRAM
I (983) heap_init: At 3FFE4350 len 0001BCB0 (111 KiB): D/IRAM
I (989) heap_init: At 40096E34 len 000091CC (36 KiB): IRAM
I (995) cpu_start: Pro cpu start user code
I (1000) spiram: Adding pool of 4096K of external SPI memory to heap allocator
I (125) cpu_start: Starting scheduler on PRO CPU.
I (0) cpu_start: Starting scheduler on APP CPU.
I (126) SD: Initializing SD card
I (126) gpio: GPIO[13]| InputEn: 0| OutputEn: 1| OpenDrain: 0| Pullup: 0| Pulldown: 0| Intr:0
Name: SA02G
Type: SDSC
Speed: 40 MHz
Size: 1876MB
SPI: display device added to spi bus (1)
SPI: attached display device, speed=8000000
SPI: bus uses native pins: false
SPI: display init...
OK
SPI: Max rd speed = 1000000
SPI: Changed speed to 26666666
I (1626) gpio: GPIO[33]| InputEn: 1| OutputEn: 0| OpenDrain: 0| Pullup: 0| Pulldown: 0| Intr:2
I (1626) gpio: GPIO[34]| InputEn: 1| OutputEn: 0| OpenDrain: 0| Pullup: 0| Pulldown: 0| Intr:2
I (1636) gpio: GPIO[35]| InputEn: 1| OutputEn: 0| OpenDrain: 0| Pullup: 0| Pulldown: 0| Intr:2
I (1646) gpio: GPIO[36]| InputEn: 1| OutputEn: 0| OpenDrain: 0| Pullup: 0| Pulldown: 0| Intr:0
I (1656) gpio: GPIO[39]| InputEn: 1| OutputEn: 0| OpenDrain: 0| Pullup: 0| Pulldown: 0| Intr:0
I (1666) AUDIO: Starting audio task
I (1676) I2S: DMA Malloc info, datalen=blocksize=256, dma_buf_count=4
I (1676) I2S: DMA Malloc info, datalen=blocksize=256, dma_buf_count=4
I (1686) I2S: APLL: Req RATE: 44100, real rate: 43945.238, BITS: 32, CLKM: 1, BCK_M: 8, MCLK: 22499962.000, SCLK: 2812495.250000, diva: 1, divb: 0
I (1906) wifi: wifi driver task: 3ffe1948, prio:23, stack:3584, core=0
I (1906) wifi: wifi firmware version: 7c00966
I (1906) wifi: config NVS flash: enabled
I (1916) wifi: config nano formating: disabled
I (1916) system_api: Base MAC address is not set, read default base MAC address from BLK0 of EFUSE
I (1926) system_api: Base MAC address is not set, read default base MAC address from BLK0 of EFUSE
I (1956) wifi: Init dynamic tx buffer num: 32
I (1956) wifi: Init data frame dynamic rx buffer num: 32
I (1956) wifi: Init management frame dynamic rx buffer num: 32
I (1956) wifi: Init management short buffer num: 32
I (1966) wifi: Init static rx buffer size: 1600
I (1966) wifi: Init static rx buffer num: 10
I (1966) wifi: Init dynamic rx buffer num: 32
I (1976) WIFI: Setting WiFi configuration SSID SPACE
ets Jun  8 2016 00:22:57

rst:0x1 (POWERON_RESET),boot:0x1b (SPI_FAST_FLASH_BOOT)
configsip: 0, SPIWP:0xee
clk_drv:0x00,q_drv:0x00,d_drv:0x00,cs0_drv:0x00,hd_drv:0x00,wp_drv:0x00
mode:DIO, clock div:1
load:0x3fff0018,len:4
load:0x3fff001c,len:6436
load:0x40078000,len:10456
load:0x40080400,len:7068

*** NO SD log:

ets Jun  8 2016 00:22:57
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
ctag-fh-kiel, 2021-09-01:
can you capture the log during boot cycling WITH SD?

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

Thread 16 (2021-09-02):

Crashes and reboots when trying to download FreeSound sound by ID

guytaylor, 2021-09-02:
Repro steps:
1. Select Sample
2. Select ID
3. Enter a valid FreeSound ID e.g. 123

Unit crashes and reboots    (My token replaced with xxxxxx)
A few observations:
* the port appears incorrect, as it should be 443
* Assuming this URL is to retrieve metadata should it include the 'format' parameter eg. 'https://freesound.org/apiv2/sounds/123/?format=json&token=xxxxxx'

Logs:

W (92316) id: 123
I (93116) HTTP_REQ: Following: https://freesound.org:80/apiv2/sounds/123/?token=xxxxxx
Guru Meditation Error: Core  0 panic'ed (LoadProhibited). Exception was unhandled.
Core 0 register dump:
PC      : 0x4018e9b7  PS      : 0x00060a30  A0      : 0x80175d84  A1      : 0x3ffecbe0
A2      : 0x00000000  A3      : 0xffffffff  A4      : 0x00000001  A5      : 0x3ffecab0
A6      : 0x00000087  A7      : 0x3ffecab0  A8      : 0x3ffae940  A9      : 0x00000087
A10     : 0x00000000  A11     : 0x3ffecaf4  A12     : 0x3ffecad4  A13     : 0x00000000
A14     : 0x0000005c  A15     : 0xff000000  SAR     : 0x00000004  EXCCAUSE: 0x0000001c
EXCVADDR: 0x00000018  LBEG    : 0x4008b535  LEND    : 0x4008b545  LCOUNT  : 0xffffffe8

ELF file SHA256: 4a55c6babb07d1bd75da8f939e30e0b3cd5f2871fb7e3cee016c99f74212d90c

Backtrace: 0x4018e9b7:0x3ffecbe0 0x40175d81:0x3ffecc00 0x4016b286:0x3ffecc20 0x4016bff6:0x3ffecc40 0x40127066:0x3ffecd00

Rebooting...

ctag-fh-kiel, 2021-09-02:
Unfortunately, I don't have an old ESP IDF up an running to fix the
firmware, this seems a problem with current freesound web services. Best
would be to port Strämpler to the latest release IDF, would you be willing
to help?

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

ctag-fh-kiel, 2021-09-02:
The freesound API has completely moved to https, thus that part in Strämpler firmware needs to be adapted. I have been able to bring the fw to IDF 4.1 as a starting point in this branch:
migrate_idf_4.x

guytaylor, 2021-09-02:
Let me give setting the dev env up a crack. :)

guytaylor, 2021-09-02:
Hi Robert,
How's it going? :)
I am happy to give it a go. I have a lot of programming experience, mainly
in C# but some C++. I have not used ESP-IDF before but have done lots of
Arduino stuff, so could I trouble you for a couple of pointers to get me
started?
Hopefully just a couple of basic things! please bear with me :)

So I'm following this guide (
https://github.com/ctag-fh-kiel/ctag-straempler/wiki/GettingStarted), and i
am working on a Windows 10 machine.
I've installed the standard ESP-IDF and that is working fine.

I've done "Installing / replacing standard ESP-IDF"
- But when I run ESP-IDF 4.3 PowerShell I get the following errors. Is this
ok?
[image: image.png]

*- GCC version*
when I type gcc --version. I get this:
gcc.exe (x86_64-posix-seh, Built by strawberryperl.com project) 8.3.0

does that mean I am ok, and don't need to install GCC?

*-- Setup ULT toolchain*
I was reading the docs and it states: "If you have already set up ESP-IDF
with CMake build system according to the Getting Started Guide
<https://docs.espressif.com/projects/esp-idf/en/latest/esp32/get-started/index.html>,
then the ULP toolchain will already be installed."
I used the windows installer, so I assume that I don't need to install this
explicitly?

So... if all the above is good, I should be set up!

Next, I did:
git clone --recursive https://github.com/ctag-fh-kiel/ctag-straempler.git

and then I tried : *make menuconfig*
but got the following error:
*C:/Users/guy/Desktop/esp-idf//make/project.mk:114 <http://project.mk:114>:
*** IDF_PATH cannot contain colons. If overriding IDF_PATH on Windows, use
MSYS Unix-style /c/dir instead of C:/dir.  Stop.*

If you notice above:
[image: image.png]
Looks like my environment path is being setup incorrectly
I even tried setting it explicitly in windows:
[image: image.png]
But no luck, I still see the same 'Setting IDF_PATH: C:/users...' when
I run powershell

Do you know how I can fix that?

I can see your new branch, so once I have the above working, I shall try
and compile that.
What state is that in? As in, if I just compile and deploy it, should the
strampler work as it does now?

Thanks!
Guy

On Fri, Sep 3, 2021 at 4:07 AM Robert Manzke ***@***.***>
wrote:

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

guytaylor, 2021-09-03:
Hey Robert, I sent you an email

ctag-fh-kiel, 2021-09-03:
Hi Guy, thanks for your help. I have been able to port Strämpler to esp idf 4.1, there were a number of significant changes.
Please check the binaries in the dev branch (folder bin/) and flash them with the flash.sh script.
Downloading from freesound should work with them.
I will cut a new public release once you confirm it works.
Strampler has now a Github action, which allows to compile the firmware in the cloud.
I will eventually write a documentation for it.
Using a docker image is the easiest way for you to get your own dev environment up and running.
You can check the action in the .github/workflows folder.
If you enable Github actions in your Github account, your can build firmwares automatically every time you push into the dev branch of your fork. Binaries are then available as draft binary under your fork's releases.

Let me know if the firmware works now.

guytaylor, 2021-09-03:
I tried to get a sample by ID from FreeSound (93727).

It didn't restart but it just sat there. I left it for about 10 minutes (it's a 900k sample, so I assume it should have downloaded in that time)
The screen had to progress indicator but the clock did continue to run.
This is what was in the logs:

I (5416) MDNS: Initialize service...
I (5416) REST-API: Starting server on port: '80', prio 5
I (5416) REST-API: Registering URI handlers
W (73386) id: 93727

ctag-fh-kiel, 2021-09-04:
Strange, it works for me, this is my log. Make sure your wifi is working
well. You can check from your laptop to access the freesound URLs directly
and see if it generally should work in your network.
https://freesound.org/apiv2/sounds/93727/?token=dKJhasdkjhasdASKdjh (use
your API token)
https://freesound.org/data/previews/93/93727_377011-hq.mp3

On the SD card you have to give the correct freesound token.
I have published this as a pre-release here:
https://github.com/ctag-fh-kiel/ctag-straempler/releases/tag/0.9-pre maybe
re-flash to this binary

I (11851) REST-API: Starting server on port: '80', prio 5

I (11851) REST-API: Registering URI handlers

W (47591) id: 93727

I (47591) fsnd:
https://freesound.org/apiv2/sounds/93727/?token=dKJhasdkjhasdASKdjh

I (49361) FSND: mp3 file info {"id":93727,"url":"
https://freesound.org/people/zgump/sounds/93727/","name":"TR LOOP
0416.wav","tags":["goa","goa-trance","goatrance","loop","psy","psy-trance","psytrance","trance"],"description":"loop
psy psy-trance psytrance trance goatrance goa-trance
goa","geotag":null,"created":"2010-03-31T17:57:23","license":"
http://creativecommons.org/publicdomain/zero/1.0/
","type":"wav","channels":2,"filesize":908150,"bitrate":1378,"bitdepth":16,"duration":5.14732,"samplerate":44100.0,"username":"zgump","pack":"
https://freesound.org/apiv2/packs/6038/","pack_name":null,"download":"
https://freesound.org/apiv2/sounds/93727/download/","bookmark":"
https://freesound.org/apiv2/sounds/93727/bookmark/
","previews":{"preview-lq-ogg":"
https://freesound.org/data/previews/93/93727_377011-lq.ogg
","preview-lq-mp3":"
https://freesound.org/data/previews/93/93727_377011-lq.mp3
","preview-hq-ogg":"
https://freesound.org/data/previews/93/93727_377011-hq.ogg
","preview-hq-mp3":"
https://freesound.org/data/previews/93/93727_377011-hq.mp3
"},"images":{"spectral_m":"
https://freesound.org/data/displays/93/93727_377011_spec_M.jpg
","spectral_l":"
https://freesound.org/data/displays/93/93727_377011_spec_L.jpg
","spectral_bw_l":"
https://freesound.org/data/displays/93/93727_377011_spec_bw_L.jpg
","waveform_bw_m":"
https://freesound.org/data/displays/93/93727_377011_wave_bw_M.png
","waveform_bw_l":"
https://freesound.org/data/displays/93/93727_377011_wave_bw_L.png
","waveform_l":"
https://freesound.org/data/displays/93/93727_377011_wave_L.png
","waveform_m":"
https://freesound.org/data/displays/93/93727_377011_wave_M.png
","spectral_bw_m":"
https://freesound.org/data/displays/93/93727_377011_spec_bw_M.jpg
"},"num_downloads":169,"avg_rating":4.6,"num_ratings":5,"rate":"
https://freesound.org/apiv2/sounds/93727/rate/","comments":"
https://freesound.org/apiv2/sounds/93727/comments/
","num_comments":0,"comment":"
https://freesound.org/apiv2/sounds/93727/comment/","similar_sounds":"
https://freesound.org/apiv2/sounds/93727/similar/","analysis":"No
descriptors specified. You should indicate which descriptors you want with
the 'descriptors' request parameter.","analysis_frames":"
https://freesound.org/data/analysis/93/93727_377011_frames.json
","analysis_stats":"https://freesound.org/apiv2/sounds/93727/analysis/","ac_analysis":{"ac_tempo_confidence":0.9896296262741089,"ac_note_confidence":0.8253257870674133,"ac_depth":18.11034269674787,"ac_note_midi":52,"ac_temporal_centroid":0.4961334764957428,"ac_warmth":38.53786932424461,"ac_loop":true,"ac_hardness":57.687418322872134,"ac_loudness":-20.077274322509766,"ac_reverb":false,"ac_roughness":47.08115554605569,"ac_log_attack_time":-0.05868467688560486,"ac_boominess":15.989786649292943,"ac_note_frequency":164.5169219970703,"ac_tempo":70,"ac_brightness":58.45493938743502,"ac_sharpness":41.63989618168988,"ac_tonality_confidence":0.8204907774925232,"ac_dynamic_range":0.7360343933105469,"ac_note_name":"E3","ac_tonality":"E
minor","ac_single_event":false}}

I (49621) ID: mp3 URL is:
https://freesound.org/data/previews/93/93727_377011-hq.mp3, fname:
/pool/93727.mp3

I (53431) FREESOUND: Completed

I (53431) Menu: Got Freesound MP3 complete!

I (85491) MP3: Decode MP3

I (85511) MP3: Infile /pool/93727.MP3, outfile /raw/93727.RAW

I (85511) MP3: nChannels 2

I (85511) MP3: Decoder task, working with: fin /pool/93727.MP3, fout
/raw/93727.RAW

I (85521) MP3: Size of mp3 file to be decoded 124425

I (85531) MP3: Decoder instantiated

I (85541) MP3: MP3 Error 0

I (85541) MP3: FrameInfo: 44100

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

guytaylor, 2021-09-04:
I tried the new binary and it worked :)
Thanks

Closed 2021-09-04.

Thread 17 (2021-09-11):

cv6 and cv7 don't work in the CV Matrix

guytaylor, 2021-09-11:
I was in the process of testing that all my CV input were working correctly.

So I tried mapping the various CV input to a property e.g. V0 Volume. (I also tried a few others)

CV3 4 altered the volume from medium loudness to full loudness (is this correct?)
CV5 and CV8 varied the volume correctly from silence to full volume
CV6 and CV 7 made to difference at all to volume

I checked the voltages on the input pins to the ADC and they all varied from 0v->3.3V

So, I assume it's a software issue?

I checked the logs but nothing seems to be logged around those operations
Thanks

ctag-fh-kiel, 2021-09-11:
Hi Guy,

CV1+2 are only for pitch CV 1V/Octave ranging from -1.5 ... 5.5 V
CV3+4 are bi-polar CV ranging from -5...5V (so if you want e.g. 0 volume,
you have to apply -5V to these ins)
CV5-8 are uni-polar CV ranging from 0...5V, their value is offset by
whatever you adjust on pots 5-8 (i.e. if you want to use external CV to
modulate, you have to move the pot position all left not to offset the
external CV)

I have checked with the current firmware you have, everything works as
expected.

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

guytaylor, 2021-09-11:
Hi,
I've worked out the problem (Maybe this is just on the Antrumbra boards)
CH6 and CH7 are reversed.  CV7 Cv source is actual hardware in CV6  and vice versa

ctag-fh-kiel, 2021-09-11:
Seems a wiring issue on the Antumbra PCBs... You could fix it in the
firmware and flash your custom fw...

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

guytaylor, 2021-09-11:
happy to try!
I had a couple of issues getting my dev env working. Did you get my email with a few questions in there? :)

ctag-fh-kiel, 2021-09-11:
Yup, I'd recommend to use a Docker image (updated the readme recently):
https://github.com/ctag-fh-kiel/ctag-straempler#build-instructions

Editing this file should help (lines 66ff):
https://github.com/ctag-fh-kiel/ctag-straempler/blob/master/components/drivers/spi_per.c

Good luck :)

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

guytaylor, 2021-09-11:
I just swapped the pins in hardware for an immediate fix!

Great, thanks. I'll give it a go. I am keen to build the firmware

ctag-fh-kiel, 2021-09-11:
Awesome :)

Closed 2021-09-11.

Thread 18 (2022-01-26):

diskio_sdmmc: sdmmc_read_blocks failed

polymer81, 2022-01-26:
Hi.

I have only tried with one SD card but this looks like there is a problem with it I guess. When I use the flash.sh file, the files are written to the card and the SD examples work fine. This is the serial monitor output :

rst:0x1 (POWERON_RESET),boot:0x1b (SPI_FAST_FLASH_BOOT)
configsip: 0, SPIWP:0xee
clk_drv:0x00,q_drv:0x00,d_drv:0x00,cs0_drv:0x00,hd_drv:0x00,wp_drv:0x00
mode:DIO, clock div:2
load:0x3fff0030,len:4
load:0x3fff0034,len:7316
load:0x40078000,len:14252
load:0x40080400,len:4688
entry 0x400806a4
 [0;32mI (28) boot: ESP-IDF v4.1.2-95-gaeb66e1057 2nd stage bootloader [0m
 [0;32mI (28) boot: compile time 09:31:00 [0m
 [0;32mI (28) boot: chip revision: 1 [0m
 [0;32mI (32) boot_comm: chip revision: 1, min. bootloader chip revision: 0 [0m
 [0;32mI (39) qio_mode: Enabling default flash chip QIO [0m
 [0;32mI (44) boot.esp32: SPI Speed      : 40MHz [0m
 [0;32mI (49) boot.esp32: SPI Mode       : QIO [0m
 [0;32mI (53) boot.esp32: SPI Flash Size : 4MB [0m
 [0;32mI (58) boot: Enabling RNG early entropy source... [0m
 [0;32mI (63) boot: Partition Table: [0m
 [0;32mI (67) boot: ## Label            Usage          Type ST Offset   Length [0m
 [0;32mI (74) boot:  0 nvs              WiFi data        01 02 00009000 00006000 [0m
 [0;32mI (82) boot:  1 phy_init         RF data          01 01 0000f000 00001000 [0m
 [0;32mI (89) boot:  2 factory          factory app      00 00 00010000 00200000 [0m
 [0;32mI (97) boot: End of partition table [0m
 [0;32mI (101) boot_comm: chip revision: 1, min. application chip revision: 0 [0m
 [0;32mI (108) esp_image: segment 0: paddr=0x00010020 vaddr=0x3f400020 size=0x2f0f0 (192752) map [0m
 [0;32mI (187) esp_image: segment 1: paddr=0x0003f118 vaddr=0x3ffb0000 size=0x00f00 (  3840) load [0m
 [0;32mI (189) esp_image: segment 2: paddr=0x00040020 vaddr=0x400d0020 size=0xc7854 (817236) map [0m
 [0;32mI (491) esp_image: segment 3: paddr=0x0010787c vaddr=0x3ffb0f00 size=0x05628 ( 22056) load [0m
 [0;32mI (501) esp_image: segment 4: paddr=0x0010ceac vaddr=0x40080000 size=0x00404 (  1028) load [0m
 [0;32mI (501) esp_image: segment 5: paddr=0x0010d2b8 vaddr=0x40080404 size=0x1e134 (123188) load [0m
 [0;32mI (579) boot: Loaded app from partition at offset 0x10000 [0m
 [0;32mI (579) boot: Disabling RNG early entropy source... [0m
 [0;32mI (580) psram: This chip is ESP32-D0WD [0m
 [0;32mI (584) spiram: Found 64MBit SPI RAM device [0m
 [0;32mI (589) spiram: SPI RAM mode: flash 80m sram 80m [0m
 [0;32mI (594) spiram: PSRAM initialized, cache is in low/high (2-core) mode. [0m
 [0;32mI (601) cpu_start: Pro cpu up. [0m
 [0;32mI (605) cpu_start: Application information: [0m
 [0;32mI (610) cpu_start: Project name:     ctag-straempler [0m
 [0;32mI (616) cpu_start: App version:      v0.9 [0m
 [0;32mI (620) cpu_start: Compile time:     Sep 11 2021 09:54:10 [0m
 [0;32mI (626) cpu_start: ELF file SHA256:  32bab0cc5eb6c006... [0m
 [0;32mI (632) cpu_start: ESP-IDF:          v4.1.2-95-gaeb66e1057 [0m
 [0;32mI (638) cpu_start: Starting app cpu, entry point is 0x40081720 [0m
 [0;32mI (0) cpu_start: App cpu up. [0m
 [0;32mI (1121) spiram: SPI SRAM memory test OK [0m
 [0;32mI (1121) heap_init: Initializing. RAM available for dynamic allocation: [0m
 [0;32mI (1121) heap_init: At 3FFAE6E0 len 00001920 (6 KiB): DRAM [0m
 [0;32mI (1128) heap_init: At 3FFBEEB0 len 00021150 (132 KiB): DRAM [0m
 [0;32mI (1134) heap_init: At 3FFE0440 len 00003AE0 (14 KiB): D/IRAM [0m
 [0;32mI (1140) heap_init: At 3FFE4350 len 0001BCB0 (111 KiB): D/IRAM [0m
 [0;32mI (1147) heap_init: At 4009E538 len 00001AC8 (6 KiB): IRAM [0m
 [0;32mI (1153) cpu_start: Pro cpu start user code [0m
 [0;32mI (1158) spiram: Adding pool of 4096K of external SPI memory to heap allocator [0m
 [0;32mI (1178) spi_flash: detected chip: generic [0m
 [0;32mI (1178) spi_flash: flash io: qio [0m
 [0;32mI (1178) cpu_start: Starting scheduler on PRO CPU. [0m
 [0;32mI (0) cpu_start: Starting scheduler on APP CPU. [0m
 [0;32mI (1188) SD: Initializing SD card [0m
 [0;32mI (1188) gpio: GPIO[13]| InputEn: 0| OutputEn: 1| OpenDrain: 0| Pullup: 0| Pulldown: 0| Intr:0  [0m
Name: SD64G
Type: SDHC/SDXC
Speed: 40 MHz
Size: 59640MB
SPI: display device added to spi bus (1)

SPI: attached display device, speed=8000000

SPI: bus uses native pins: false

SPI: display init...

OK

SPI: Max rd speed = 1000000

SPI: Changed speed to 26666666

 [0;32mI (2688) gpio: GPIO[33]| InputEn: 1| OutputEn: 0| OpenDrain: 0| Pullup: 0| Pulldown: 0| Intr:2  [0m
 [0;32mI (2688) gpio: GPIO[34]| InputEn: 1| OutputEn: 0| OpenDrain: 0| Pullup: 0| Pulldown: 0| Intr:2  [0m
 [0;32mI (2698) gpio: GPIO[35]| InputEn: 1| OutputEn: 0| OpenDrain: 0| Pullup: 0| Pulldown: 0| Intr:2  [0m
 [0;32mI (2708) gpio: GPIO[36]| InputEn: 1| OutputEn: 0| OpenDrain: 0| Pullup: 0| Pulldown: 0| Intr:0  [0m
 [0;32mI (2718) gpio: GPIO[39]| InputEn: 1| OutputEn: 0| OpenDrain: 0| Pullup: 0| Pulldown: 0| Intr:0  [0m
 [0;32mI (2728) AUDIO: Starting audio task [0m
 [0;32mI (2728) I2S: DMA Malloc info, datalen=blocksize=256, dma_buf_count=4 [0m
 [0;32mI (2738) I2S: DMA Malloc info, datalen=blocksize=256, dma_buf_count=4 [0m
 [0;32mI (2758) I2S: APLL: Req RATE: 44100, real rate: 44099.988, BITS: 32, CLKM: 1, BCK_M: 8, MCLK: 22579194.000, SCLK: 2822399.250000, diva: 1, divb: 0 [0m
 [0;31mE (2798) sdmmc_cmd: sdmmc_read_sectors_dma: sdmmc_send_cmd returned 0x109 [0m
 [0;31mE (2798) diskio_sdmmc: sdmmc_read_blocks failed (265) [0m
 [0;31mE (2798) FILEIO: Error reading from file [0m
 [0;31mE (2798) PRESET: Root is NULL [0m
 [0;31mE (2808) MENU: Error loading bank from file [0m
 [0;31mE (2808) MENU: Error loading bank [0m
 [0;31mE (2818) sdmmc_cmd: sdmmc_read_sectors_dma: sdmmc_send_cmd returned 0x107 [0m
 [0;31mE (2818) diskio_sdmmc: sdmmc_read_blocks failed (263) [0m
 [0;31mE (2828) FILEIO: Could not allocate memory [0m
 [0;31mE (2828) MENU: Error loading tz_shift from config [0m
I (2988) wifi:wifi driver task: 3ffe9e1c, prio:23, stack:6656, core=0
 [0;32mI (2988) system_api: Base MAC address is not set, read default base MAC address from BLK0 of EFUSE [0m
 [0;32mI (2988) system_api: Base MAC address is not set, read default base MAC address from BLK0 of EFUSE [0m
I (3008) wifi:wifi firmware version: 1424aca
I (3008) wifi:config NVS flash: enabled
I (3008) wifi:config nano formating: disabled
I (3008) wifi:Init data frame dynamic rx buffer num: 32
I (3018) wifi:Init management frame dynamic rx buffer num: 32
I (3018) wifi:Init management short buffer num: 32
I (3028) wifi:Init static tx buffer num: 16
I (3028) wifi:Init static rx buffer size: 1600
I (3038) wifi:Init static rx buffer num: 10
I (3038) wifi:Init dynamic rx buffer num: 32
 [0;32mI (3048) wifi_init: rx ba win: 16 [0m
 [0;32mI (3048) wifi_init: tcpip mbox: 32 [0m
 [0;32mI (3048) wifi_init: udp mbox: 6 [0m
 [0;32mI (3058) wifi_init: tcp mbox: 6 [0m
 [0;32mI (3058) wifi_init: tcp tx win: 5744 [0m
 [0;32mI (3068) wifi_init: tcp rx win: 5744 [0m
 [0;32mI (3068) wifi_init: tcp mss: 1440 [0m
 [0;32mI (3068) wifi_init: WiFi/LWIP prefer SPIRAM [0m
 [0;32mI (3078) wifi_init: WiFi IRAM OP enabled [0m
 [0;32mI (3078) wifi_init: WiFi RX IRAM OP enabled [0m
 [0;31mE (3088) sdmmc_req: handle_idle_state_events unhandled: 00000008 00000002 [0m
 [0;32mI (3098) WIFI: Setting WiFi configuration SSID Fantasy Man [0m
 [0;32mI (3098) phy_init: phy_version 4660,0162888,Dec 23 2020 [0m
 [0;33mW (3108) phy_init: failed to load RF calibration data (0x1102), falling back to full calibration [0m
ets Jun  8 2016 00:22:57

rst:0x1 (POWERON_RESET),boot:0x1b (SPI_FAST_FLASH_BOOT)
configsip: 0, SPIWP:0⸮⸮半⸮⸮⸮_drv:0x00,q_drv:0x00,d_drv:0x00,c⸮ߤ⸮⸮⸮⸮⸮⸮⸮⸮hd_drv:0x00,wp_drv:0x00
mode:DIO, clock div:2
load:0x3fff0030,len:4
load:0x3fff0034,len:7316
load:0x40078000,len:14252
load:0x40080400,len:4688
entry 0x400806a4
 [0;32mI (28) boot: ESP-IDF v4.1.2-95-gaeb66e1057 2nd stage bootloader [0m
 [0;32mI (28) boot: compile time 09:31:00 [0m
 [0;32mI (28) boot: chip revision: 1 [0m
 [0;32mI (32) boot_comm: chip revision: 1, min. bootloader chip revision: 0 [0m
 [0;32mI (39) qio_mode: Enabling default flash chip QIO [0m
 [0;32mI (44) boot.esp32: SPI Speed      : 40MHz [0m
 [0;32mI (49) boot.esp32: SPI Mode       : QIO [0m
 [0;32mI (53) boot.esp32: SPI Flash Size : 4MB [0m
 [0;32mI (58) boot: Enabling RNG early entropy source... [0m
 [0;32mI (63) boot: Partition Table: [0m
 [0;32mI (67) boot: ## Label            Usage          Type ST Offset   Length [0m
 [0;32mI (74) boot:  0 nvs              WiFi data        01 02 00009000 00006000 [0m
 [0;32mI (82) boot:  1 phy_init         RF data          01 01 0000f000 00001000 [0m
 [0;32mI (89) boot:  2 factory          factory app      00 00 00010000 00200000 [0m
 [0;32mI (97) boot: End of partition table [0m
 [0;32mI (101) boot_comm: chip revision: 1, min. application chip revision: 0 [0m
 [0;32mI (108) esp_image: segment 0: paddr=0x00010020 vaddr=0x3f400020 size=0x2f0f0 (192752) map [0m
 [0;32mI (187) esp_image: segment 1: paddr=0x0003f118 vaddr=0x3ffb0000 size=0x00f00 (  3840) load [0m
 [0;32mI (189) esp_image: segment 2: paddr=0x00040020 vaddr=0x400d0020 size=0xc7854 (817236) map [0m
 [0;32mI (491) esp_image: segment 3: paddr=0x0010787c vaddr=0x3ffb0f00 size=0x05628 ( 22056) load [0m
 [0;32mI (501) esp_image: segment 4: paddr=0x0010ceac vaddr=0x40080000 size=0x00404 (  1028) load [0m
 [0;32mI (501) esp_image: segment 5: paddr=0x0010d2b8 vaddr=0x40080404 size=0x1e134 (123188) load [0m
 [0;32mI (579) boot: Loaded app from partition at offset 0x10000 [0m
 [0;32mI (579) boot: Disabling RNG early entropy source... [0m
 [0;32mI (580) psram: This chip is ESP32-D0WD [0m
 [0;32mI (584) spiram: Found 64MBit SPI RAM device [0m
 [0;32mI (589) spiram: SPI RAM mode: flash 80m sram 80m [0m
 [0;32mI (594) spiram: PSRAM initialized, cache is in low/high (2-core) mode. [0m
 [0;32mI (601) cpu_start: Pro cpu up. [0m
 [0;32mI (605) cpu_start: Application information: [0m
 [0;32mI (610) cpu_start: Project name:     ctag-straempler [0m
 [0;32mI (616) cpu_start: App version:      v0.9 [0m
 [0;32mI (620) cpu_start: Compile time:     Sep 11 2021 09:54:10 [0m
 [0;32mI (626) cpu_start: ELF file SHA256:  32bab0cc5eb6c006... [0m
 [0;32mI (632) cpu_start: ESP-IDF:          v4.1.2-95-gaeb66e1057 [0m
 [0;32mI (638) cpu_start: Starting app cpu, entry point is 0x40081720 [0m
 [0;32mI (0) cpu_start: App cpu up. [0m
 [0;32mI (1121) spiram: SPI SRAM memory test OK [0m
 [0;32mI (1121) heap_init: Initializing. RAM available for dynamic allocation: [0m
 [0;32mI (1121) heap_init: At 3FFAE6E0 len 00001920 (6 KiB): DRAM [0m
 [0;32mI (1128) heap_init: At 3FFBEEB0 len 00021150 (132 KiB): DRAM [0m
 [0;32mI (1134) heap_init: At 3FFE0440 len 00003AE0 (14 KiB): D/IRAM [0m
 [0;32mI (1140) heap_init: At 3FFE4350 len 0001BCB0 (111 KiB): D/IRAM [0m
 [0;32mI (1147) heap_init: At 4009E538 len 00001AC8 (6 KiB): IRAM [0m
 [0;32mI (1153) cpu_start: Pro cpu start user code [0m
 [0;32mI (1158) spiram: Adding pool of 4096K of external SPI memory to heap allocator [0m
 [0;32mI (1178) spi_flash: detected chip: generic [0m
 [0;32mI (1178) spi_flash: flash io: qio [0m
 [0;32mI (1178) cpu_start: Starting scheduler on PRO CPU. [0m
 [0;32mI (0) cpu_start: Starting scheduler on APP CPU. [0m
 [0;32mI (1188) SD: Initializing SD card [0m
 [0;32mI (1188) gpio: GPIO[13]| InputEn: 0| OutputEn: 1| OpenDrain: 0| Pullup: 0| Pulldown: 0| Intr:0  [0m
Name: SD64G
Type: SDHC/SDXC
Speed: 40 MHz
Size: 59640MB
SPI: display device added to spi bus (1)

SPI: attached display device, speed=8000000

SPI: bus uses native pins: false

SPI: display init...

I guess I should try another SD card ?

Thanks :)

ctag-fh-kiel, 2022-01-27:
Check all solder points, try another SD card, could well be a cold solder
point, I'd say...

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

polymer81, 2022-01-27:
I will resolder the joints just in case and get another SD card. When I use examples from the SD library I can read / write without problems. When the SD card is removed it also reboots in a loop. I will start with the solder joints.
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

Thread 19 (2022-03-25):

The module is rebooting

Synthwall, 2022-03-25:
When accessing almost any menu item, the module is loaded. Upon entering the SLOT menu, the module will immediately reboot. The presence of an SD card in the slot does not affect this in any way. I think that the problem is in the firmware, maybe I did something wrong. I tried to remove all microcircuits to eliminate their influence, but it did not help. WiFi my phone does not detect from the module, I can not change the wifi settings either. Flashed via USB port, Windows 10. Software -ESP32 Download-Tool v3.6.4
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

ctag-fh-kiel, 2022-03-27:
Are you using a freshly FAT32 formated SD card? Try a few different ones, some cards don't seem to work reliably with the ESP32...

Synthwall, 2022-03-28:
Presence or absence
SD card does not affect this, I tried to change. I don't see the CLK signal on the SD card, the ESP32 doesn't seem to be accessing it at all

ctag-fh-kiel, 2022-03-28:
Are you using FW release 0.9?
Can you connect a USB cable to the monitor and start a terminal to capture any error messages on boot/reboot?

Synthwall, 2022-03-28:
Yes, software v0.9 I'm not familiar with ESP32, can you explain how to do it under Windows 10?

ctag-fh-kiel, 2022-03-28:
You could use [Putty](https://www.chiark.greenend.org.uk/~sgtatham/putty/latest.html) to connect through USB serial to the ESP.

Synthwall, 2022-03-28:
how to set up the program correctly?
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

Synthwall, 2022-03-28:
https://youtu.be/lpRoRWvhGiA

ctag-fh-kiel, 2022-03-28:
Check in windows device manager if the CP2102 USB to serial bridge is
recognized. Then use that COM port in Putty, set the baud rate to 115200
baud and connect. Then you should see error messages from the ESP.

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

Synthwall, 2022-03-28:
ets Jun  8 2016 00:22:57

rst:0x1 (POWERON_RESET),boot:0x1b (SPI_FAST_FLASH_BOOT)
configsip: 0, SPIWP:0xee
clk_drv:0x00,q_drv:0x00,d_drv:0x00,cs0_drv:0x00,hd_drv:0x00,wp_drv:0x00
mode:DIO, clock div:1
load:0x3fff0030,len:4
load:0x3fff0034,len:7316
load:0x40078000,len:14252
load:0x40080400,len:4688
entry 0x400806a4
I (28) boot: ESP-IDF v4.1.2-95-gaeb66e1057 2nd stage bootloader
I (29) boot: compile time 09:31:00
I (29) boot: chip revision: 1
I (33) boot_comm: chip revision: 1, min. bootloader chip revision: 0
I (40) qio_mode: Enabling default flash chip QIO
I (45) boot.esp32: SPI Speed      : 80MHz
I (50) boot.esp32: SPI Mode       : QIO
I (54) boot.esp32: SPI Flash Size : 4MB
I (59) boot: Enabling RNG early entropy source...
I (64) boot: Partition Table:
I (68) boot: ## Label            Usage          Type ST Offset   Length
I (75) boot:  0 nvs              WiFi data        01 02 00009000 00006000
I (82) boot:  1 phy_init         RF data          01 01 0000f000 00001000
I (90) boot:  2 factory          factory app      00 00 00010000 00200000
I (97) boot: End of partition table
I (102) boot_comm: chip revision: 1, min. application chip revision: 0
I (109) esp_image: segment 0: paddr=0x00010020 vaddr=0x3f400020 size=0x2f0f0 (19                                                                                                                                                             2752) map
I (182) esp_image: segment 1: paddr=0x0003f118 vaddr=0x3ffb0000 size=0x00f00 (                                                                                                                                                               3840) load
I (183) esp_image: segment 2: paddr=0x00040020 vaddr=0x400d0020 size=0xc7854 (81                                                                                                                                                             7236) map
I (459) esp_image: segment 3: paddr=0x0010787c vaddr=0x3ffb0f00 size=0x05628 ( 2                                                                                                                                                             2056) load
I (467) esp_image: segment 4: paddr=0x0010ceac vaddr=0x40080000 size=0x00404 (                                                                                                                                                               1028) load
I (468) esp_image: segment 5: paddr=0x0010d2b8 vaddr=0x40080404 size=0x1e134 (12                                                                                                                                                             3188) load
I (540) boot: Loaded app from partition at offset 0x10000
I (540) boot: Disabling RNG early entropy source...
I (541) psram: This chip is ESP32-D0WD
I (545) spiram: Found 64MBit SPI RAM device
I (550) spiram: SPI RAM mode: flash 80m sram 80m
I (555) spiram: PSRAM initialized, cache is in low/high (2-core) mode.
I (562) cpu_start: Pro cpu up.
I (566) cpu_start: Application information:
I (571) cpu_start: Project name:     ctag-straempler
I (576) cpu_start: App version:      v0.9
I (581) cpu_start: Compile time:     Sep 11 2021 09:54:10
I (587) cpu_start: ELF file SHA256:  32bab0cc5eb6c006...
I (593) cpu_start: ESP-IDF:          v4.1.2-95-gaeb66e1057
I (599) cpu_start: Starting app cpu, entry point is 0x40081720
I (0) cpu_start: App cpu up.
I (1082) spiram: SPI SRAM memory test OK
I (1082) heap_init: Initializing. RAM available for dynamic allocation:
I (1082) heap_init: At 3FFAE6E0 len 00001920 (6 KiB): DRAM
I (1089) heap_init: At 3FFBEEB0 len 00021150 (132 KiB): DRAM
I (1095) heap_init: At 3FFE0440 len 00003AE0 (14 KiB): D/IRAM
I (1101) heap_init: At 3FFE4350 len 0001BCB0 (111 KiB): D/IRAM
I (1108) heap_init: At 4009E538 len 00001AC8 (6 KiB): IRAM
I (1114) cpu_start: Pro cpu start user code
I (1119) spiram: Adding pool of 4096K of external SPI memory to heap allocator
I (1139) spi_flash: detected chip: gd
I (1139) spi_flash: flash io: qio
W (1139) spi_flash: Detected size(16384k) larger than the size in the binary ima                                                                                                                                                             ge header(4096k). Using the size in the binary image header.
I (1151) cpu_start: Starting scheduler on PRO CPU.
I (0) cpu_start: Starting scheduler on APP CPU.
I (1161) SD: Initializing SD card
I (1161) gpio: GPIO[13]| InputEn: 0| OutputEn: 1| OpenDrain: 0| Pullup: 0| Pulld                                                                                                                                                             own: 0| Intr:0
W (1211) vfs_fat_sdmmc: failed to mount card (13)
E (1211) SD: Failed to mount filesystem. If you want the card to be formatted, s                                                                                                                                                             et format_if_mount_failed = true.
SPI: display device added to spi bus (1)
SPI: attached display device, speed=8000000
SPI: bus uses native pins: false
SPI: display init...
OK
SPI: Max rd speed = 1000000
SPI: Changed speed to 26666666
I (2671) gpio: GPIO[33]| InputEn: 1| OutputEn: 0| OpenDrain: 0| Pullup: 0| Pulld                                                                                                                                                             own: 0| Intr:2
I (2671) gpio: GPIO[34]| InputEn: 1| OutputEn: 0| OpenDrain: 0| Pullup: 0| Pulld                                                                                                                                                             own: 0| Intr:2
I (2681) gpio: GPIO[35]| InputEn: 1| OutputEn: 0| OpenDrain: 0| Pullup: 0| Pulld                                                                                                                                                             own: 0| Intr:2
I (2691) gpio: GPIO[36]| InputEn: 1| OutputEn: 0| OpenDrain: 0| Pullup: 0| Pulld                                                                                                                                                             own: 0| Intr:0
I (2701) gpio: GPIO[39]| InputEn: 1| OutputEn: 0| OpenDrain: 0| Pullup: 0| Pulld                                                                                                                                                             own: 0| Intr:0
I (2711) AUDIO: Starting audio task
I (2711) I2S: DMA Malloc info, datalen=blocksize=256, dma_buf_count=4
I (2721) I2S: DMA Malloc info, datalen=blocksize=256, dma_buf_count=4
I (2741) I2S: APLL: Req RATE: 44100, real rate: 44099.988, BITS: 32, CLKM: 1, BC                                                                                                                                                             K_M: 8, MCLK: 22579194.000, SCLK: 2822399.250000, diva: 1, divb: 0
E (2751) FILEIO: Could not open file /sdcard/CONFIG.JSN for reading
E (2751) AUDIO: Couldn't open config.jsn
E (2761) FILEIO: Could not open file /sdcard/CONFIG.JSN for reading
E (2761) FILEIO: Could not open file /sdcard/banks/DEFAULT.JSN for reading
E (2771) PRESET: Root is NULL
E (2781) MENU: Error loading bank from file
E (2781) MENU: Error loading bank
E (2781) FILEIO: Could not open file /sdcard/CONFIG.JSN for reading
E (2791) MENU: Error loading tz_shift from config
I (2951) wifi:wifi driver task: 3ffdd77c, prio:23, stack:6656, core=0
I (2951) system_api: Base MAC address is not set, read default base MAC address                                                                                                                                                              from BLK0 of EFUSE
I (2951) system_api: Base MAC address is not set, read default base MAC address                                                                                                                                                              from BLK0 of EFUSE
I (2971) wifi:wifi firmware version: 1424aca
I (2971) wifi:config NVS flash: enabled
I (2971) wifi:config nano formating: disabled
I (2971) wifi:Init data frame dynamic rx buffer num: 32
I (2981) wifi:Init management frame dynamic rx buffer num: 32
I (2981) wifi:Init management short buffer num: 32
I (2991) wifi:Init static tx buffer num: 16
I (2991) wifi:Init static rx buffer size: 1600
I (3001) wifi:Init static rx buffer num: 10
I (3001) wifi:Init dynamic rx buffer num: 32
I (3011) wifi_init: rx ba win: 16
I (3011) wifi_init: tcpip mbox: 32
I (3011) wifi_init: udp mbox: 6
I (3021) wifi_init: tcp mbox: 6
I (3021) wifi_init: tcp tx win: 5744
I (3021) wifi_init: tcp rx win: 5744
I (3031) wifi_init: tcp mss: 1440
I (3031) wifi_init: WiFi/LWIP prefer SPIRAM
I (3041) wifi_init: WiFi IRAM OP enabled
I (3041) wifi_init: WiFi RX IRAM OP enabled
E (3051) FILEIO: Could not open file /sdcard/CONFIG.JSN for reading
E (3051) FILEIO: root == NULL
I (3061) WIFI: Setting WiFi configuration SSID ▒?
I (3061) phy_init: phy_version 4660,0162888,Dec 23 2020
I (3161) wifi:mode : sta (a8:48:fa:5a:a6:c4)

Synthwall, 2022-03-28:
Brilliant! Working! Thanks bro!)

ctag-fh-kiel, 2022-03-28:
Perfect, have fun :)

Closed 2022-03-28.

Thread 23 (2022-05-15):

Encoder direction

bretdennison, 2022-05-15:
Is there a way to reverse the encoder direction?
Thanks

ctag-fh-kiel, 2022-05-17:
You would have to build your own firmware. If you configure the project with idf.py menuconfig, there is a configuration option to invert the encoder.
If you clone the repository on Github, you can use the Github action to build the firmware in the cloud. However, before doing that you would have to manually edit the sdkconfig.default file and comment out line 125 (CONFIG_SWAP_ENCODER_PINS=y). That would be the equivalent of doing it with idf.py menuconfig.

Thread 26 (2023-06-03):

Display just stays white...

stilltryin, 2023-06-03:
Hi,  have an issue to get the display to work its a slightly different one from ali express with jumper on the back. So probably there is a =nother driver and that's why it doesn't work or something with the connection i guess...order a new display and will try that first...if its SPI connection what's the prob, how can i test?

Thanks and awesome keep up the good work...also some small advice: maybe write a bit more about the software part. PIN 6 to Ground to flash and such like that would be helpful:)

ctag-fh-kiel, 2023-06-04:
Did you bridge JP101? It's a solder jumper, which connects the SPI out (MISO) from the display to the ESP, it shouldn't matter, as the display is receiving data only.
Check all display connections, pg. 1 and pg. 5 of the schematic. If you have an oscilloscope, you can check if signals arrive on the display pins, CS (chip select), DC, SDI, SCK, those are effectively SPI pins.
The display needs to be configured to SPI mode, if it is a multi-bus type display.
Let me know how it goes...

stilltryin, 2023-06-08:
Thanks for the help...measured and fixed

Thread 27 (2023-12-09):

Cannot access freesounds.org

deepiain, 2023-12-09:
I have built and flashed the unit OK, it goes online, (the time updates) but when i go to slots/slot 1/freesounds.org nothing happens. I have checked the setup file and the api key matches my key on freesounds. not sure what to try now?

ctag-fh-kiel, 2023-12-09:
You have to download the files from Freesound first. See e.g. this video:
https://youtu.be/zmj8tKPHV8g?si=JyRLGDA9_HxLYXsa
sample->id enter the freesound sound id here and Strämpler will download the file from Freesound
This sound e.g. has the id 714254:
https://freesound.org/people/strangehorizon/sounds/714254/

Once the file has been downloaded, it is stored on your local SD-card, then you can access it with slots->freesound

deepiain, 2023-12-09:
AAAAH! it lives :) thank you so much

deepiain, 2023-12-09:
resolved

Closed 2023-12-09.

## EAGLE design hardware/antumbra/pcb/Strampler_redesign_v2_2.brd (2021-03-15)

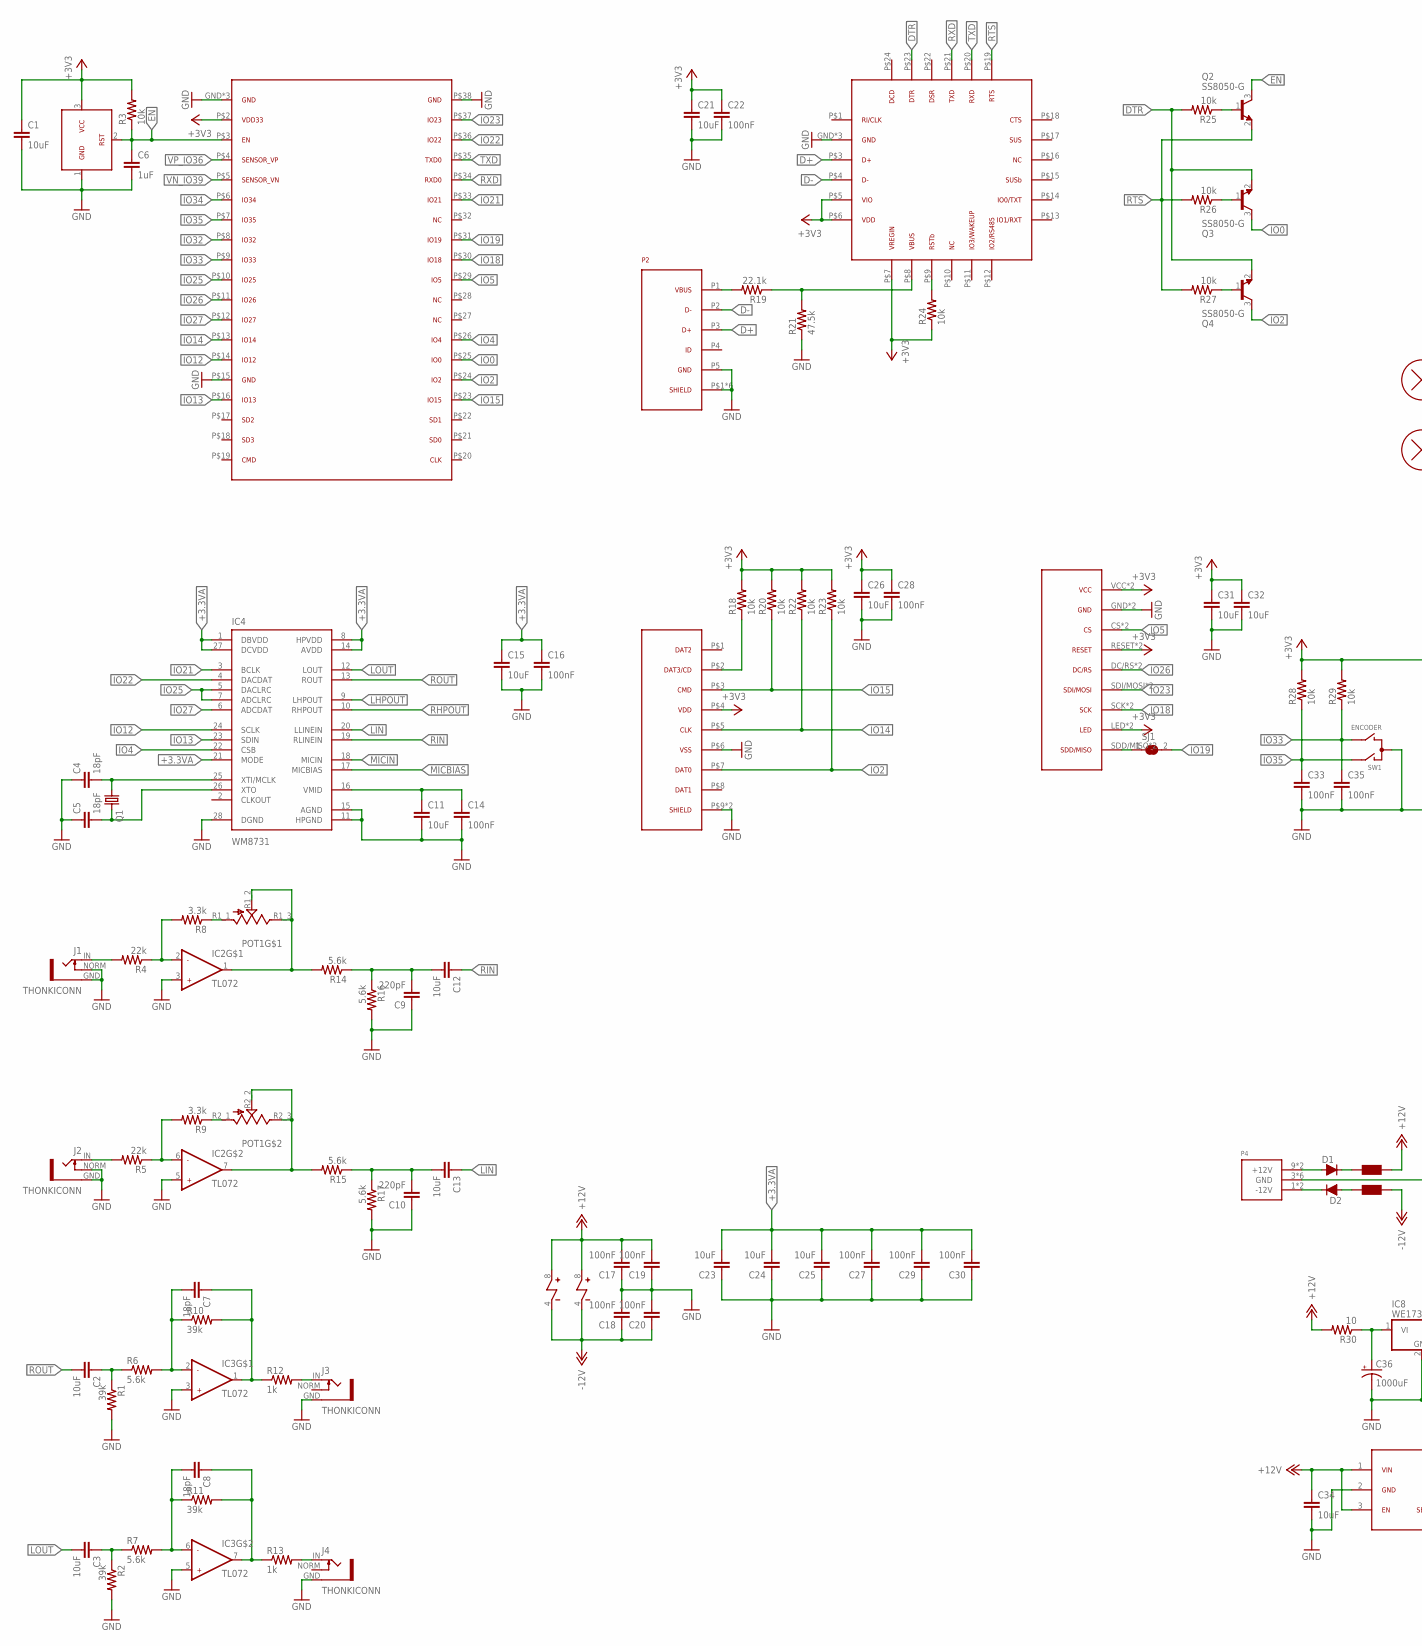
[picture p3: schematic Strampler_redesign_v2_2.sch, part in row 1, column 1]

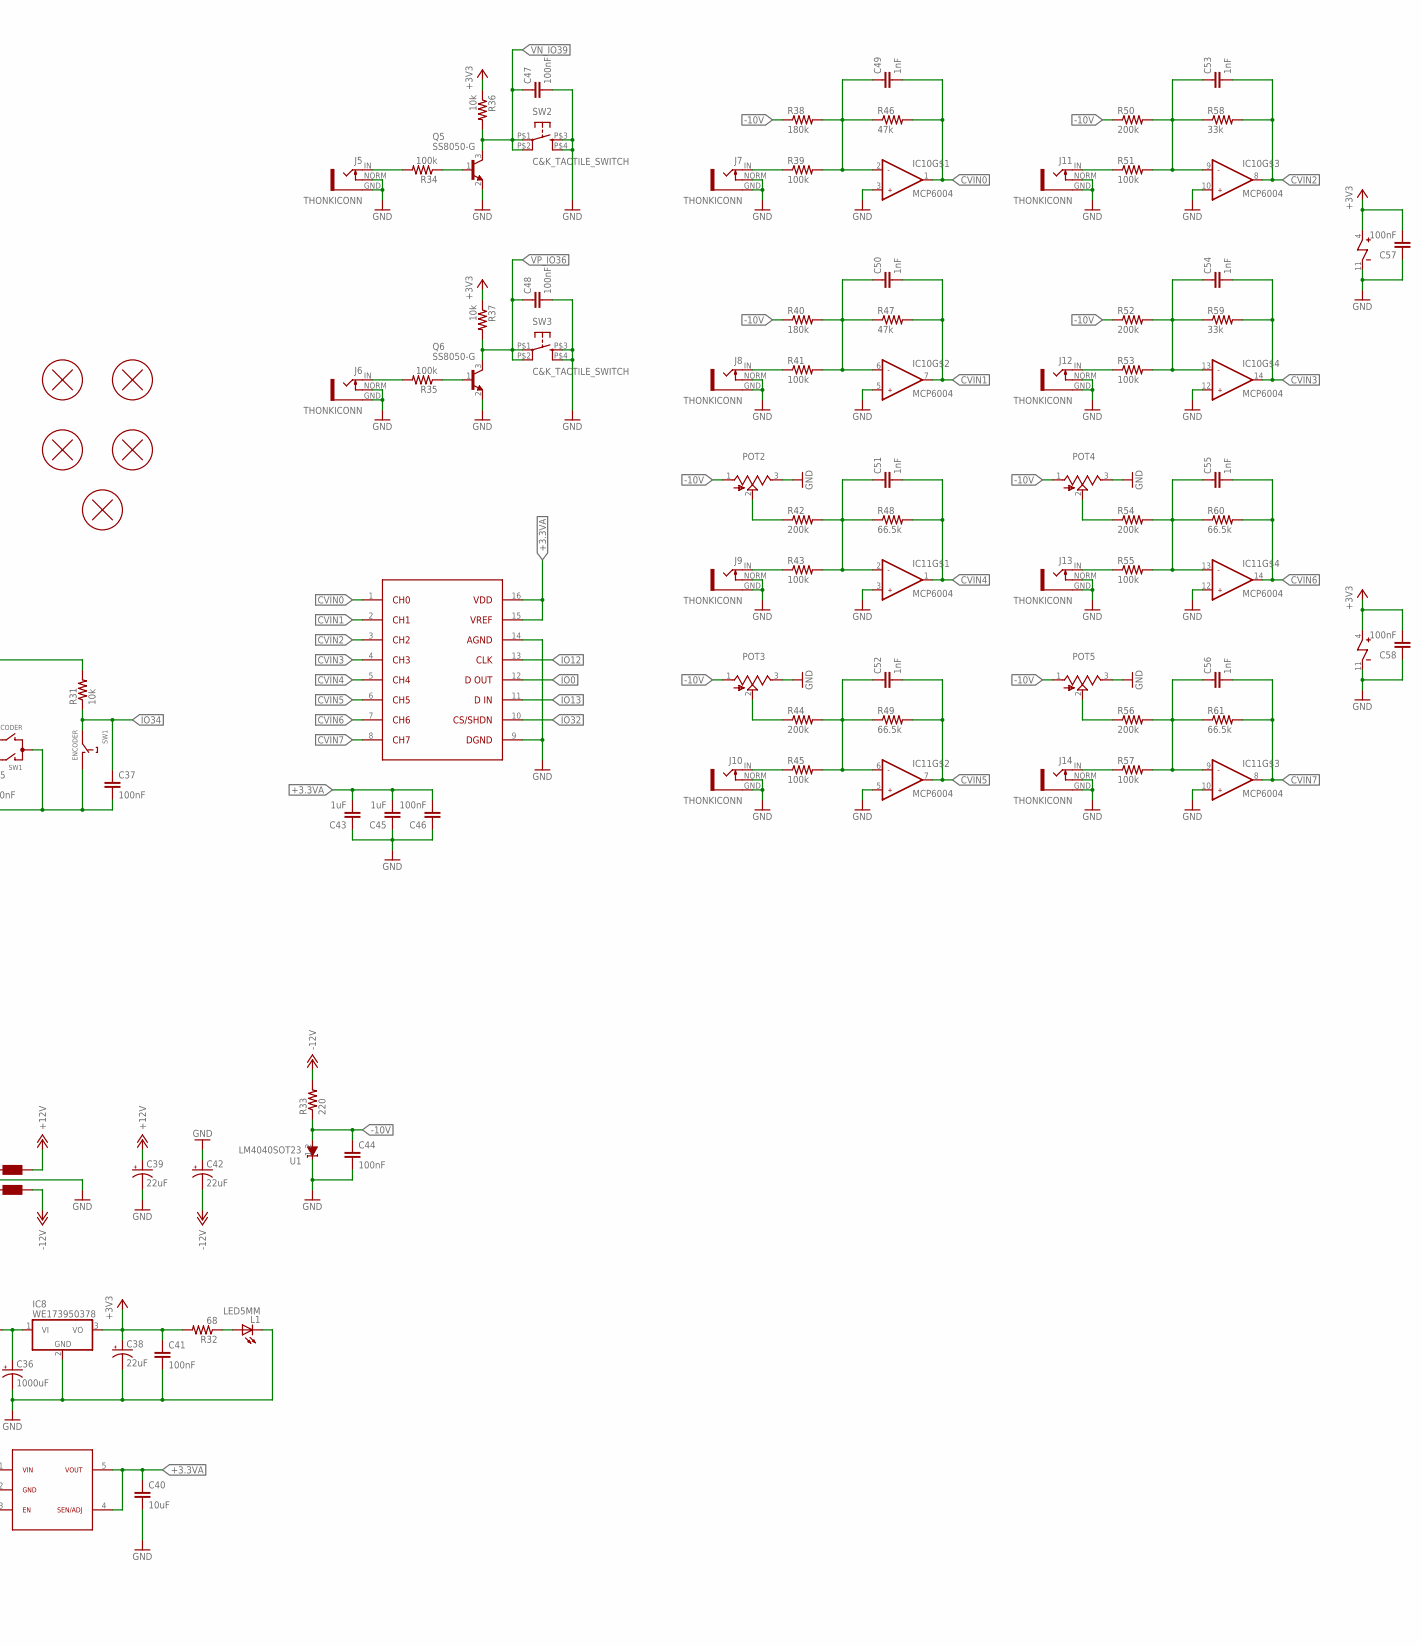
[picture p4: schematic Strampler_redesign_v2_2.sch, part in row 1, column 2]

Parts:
C1, C2, C3, C11, C12, C13, C15, C21, C23, C24, C25, C26, C31, C32, C40: 10uF; R0805
C4, C5, C7, C8: 18pF; RESISTOR_0603
C6, C43, C45: 1uF; RESISTOR_0603
C9, C10: 220pF; RESISTOR_0603
C14, C16, C17, C18, C19, C20, C22, C27, C28, C29, C30, C33, C35, C37, C41, C44, C46, C47, C48, C57, C58: 100nF; RESISTOR_0603
C34: 10uF; R1210
C36: 1000uF; PANASONIC_G
C38, C39, C42: 22uF; 1206_POL
C49, C50, C51, C52, C53, C54, C55, C56: 1nF; RESISTOR_0603
D1, D2: DIODE; SOD123
F1, F2: FERRITE-BEAD0805; R0805
H1, H2, H3, H4, H5: PCB_SCREW
IC1: MIC803; SOT23
IC2, IC3: TL072; SOIC8
IC4: WM8731; SSOP28
IC5: ESP32-WROVER-B
IC6: CP2102N
IC7: ADP7118; SOT23-5L
IC8: WE173950378; WE78
IC9: MCP3208; SOIC16
IC10, IC11: MCP6004; TSSOP14
J1, J2, J3, J4, J5, J6, J7, J8, J9, J10, J11, J12, J13, J14: THONKICONN; PROTOJACK
L1: LED5MM; LED_5MM
P1: SD-CARD; SD-CARD-THONK
P2: USB-B; USB-B-MOLEX-1050170001
P3: MSP2202_DISPLAY
P4: POWER_SIMPLE10; POWER_10
POT1: POT_DUAL_THONK
POT2, POT3, POT4, POT5: POT_VERTICAL; ALPS_POT_VERTICAL
Q1: CRYSTAL; HC49UP
Q2, Q3, Q4, Q5, Q6: SS8050-G; SOT23
R1, R2, R10, R11: 39k; RESISTOR_0603
R3, R18, R20, R22, R23, R24, R25, R26, R27, R28, R29, R31, R36, R37: 10k; RESISTOR_0603
R4, R5: 22k; RESISTOR_0603
R6, R7, R14, R15, R16, R17: 5.6k; RESISTOR_0603
R8, R9: 3.3k; RESISTOR_0603
R12, R13: 1k; RESISTOR_0603
R19: 22.1k; RESISTOR_0603
R21: 47.5k; RESISTOR_0603
R30: 10; R2512
R32: 68; RESISTOR_0603
R33: 220; RESISTOR_0603
R34, R35, R39, R41, R43, R45, R51, R53, R55, R57: 100k; RESISTOR_0603
R38, R40: 180k; RESISTOR_0603
R42, R44, R50, R52, R54, R56: 200k; RESISTOR_0603
R46, R47: 47k; RESISTOR_0603
R48, R49, R60, R61: 66.5k; RESISTOR_0603
R58, R59: 33k; RESISTOR_0603
SJ1: SJ
SW1: ENCODER; ALPS_EC12E_SW
SW2, SW3: C&K_TACTILE_SWITCH
U1: LM4040SOT23; SOT23

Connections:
+3.3VA: C15.1, C16.1, C23.2, C24.2, C25.2, C27.2, C29.2, C30.2, C40.1, C43.2, C45.2, C46.2, IC4.1 (DBVDD), IC4.8 (HPVDD), IC4.14 (AVDD), IC4.21 (MODE), IC4.27 (DCVDD), IC7.4, IC7.5, IC9.15, IC9.16
+3V3: C1.1, C21.1, C22.1, C26.1, C28.1, C31.1, C32.1, C38.2 (+), C41.1, C57.2, C58.2, IC1.3, IC5.P$2, IC6.P$5, IC6.P$6, IC6.P$7, IC8.3 (VO), IC10.4, IC11.4, P1.P$4, P3.LED, P3.LED1, P3.RESET, P3.RESET1, P3.VCC, P3.VCC1, R3.2, R18.2, R20.2, R22.2, R23.2, R24.1, R28.2, R29.2, R31.2, R32.2, R36.1, R37.1
+12V: C17.2, C19.2, C34.1, C39.2 (+), F1.1, IC2.8, IC3.8, IC7.1, IC7.3, R30.2
-10V: C44.1, POT2.1 (A), POT3.1 (A), POT4.1 (A), POT5.1 (A), R33.1, R38.1, R40.1, R50.1, R52.1, U1.2 (A)
-12V: C18.1, C20.1, C42.1 (-), F2.1, IC2.4, IC3.4, R33.2
CVIN0: C49.2, IC9.1, IC10.1, R46.2
CVIN1: C50.2, IC9.2, IC10.7, R47.2
CVIN2: C53.2, IC9.3, IC10.8, R58.2
CVIN3: C54.2, IC9.4, IC10.14, R59.2
CVIN4: C51.2, IC9.5, IC11.1, R48.2
CVIN5: C52.2, IC9.6, IC11.7, R49.2
CVIN6: C55.2, IC9.7, IC11.14, R60.2
CVIN7: C56.2, IC9.8, IC11.8, R61.2
D+: IC6.P$3, P2.P3
D-: IC6.P$4, P2.P2
DTR: IC6.P$23, Q3.2 (E), Q4.2 (E), R25.2
EN: C6.1, IC1.2, IC5.P$3, Q2.3 (C), R3.1
GND: C1.2, C4.1, C5.1, C6.2, C9.1, C10.1, C11.2, C14.2, C15.2, C16.2, C17.1, C18.2, C19.1, C20.2, C21.2, C22.2, C23.1, C24.1, C25.1, C26.2, C27.1, C28.2, C29.1, C30.1, C31.2, C32.2, C33.2, C34.2, C35.2, C36.-, C37.2, C38.1 (-), C39.1 (-), C40.2, C41.2, C42.2 (+), C43.1, C44.2, C45.1, C46.1, C47.2, C48.2, C57.1, C58.1, IC1.1, IC2.3, IC2.5, IC3.3, IC3.5, IC4.11 (HPGND), IC4.15 (AGND), IC4.28 (DGND), IC5.GND, IC5.GND2, IC5.P$1, IC5.P$15, IC5.P$38, IC6.GND, IC6.GND2, IC6.P$2, IC7.2, IC8.2 (GND), IC9.9, IC9.14, IC10.3, IC10.5, IC10.10, IC10.11, IC10.12, IC11.3, IC11.5, IC11.10, IC11.11, IC11.12, J1.GND, J1.NORM, J2.GND, J2.NORM, J3.GND, J4.GND, J5.GND, J5.NORM, J6.GND, J6.NORM, J7.GND, J7.NORM, J8.GND, J8.NORM, J9.GND, J9.NORM, J10.GND, J10.NORM, J11.GND, J11.NORM, J12.GND, J12.NORM, J13.GND, J13.NORM, J14.GND, J14.NORM, L1.K (C), P1.P$6, P1.P$9, P1.P$10, P2.P5, P2.P$1, P2.P$2, P2.P$8, P2.P$9, P2.P$10, P2.P$11, P3.GND, P3.GND1, P4.3 (GND), P4.4 (GND), P4.5 (GND), P4.6 (GND), P4.7 (GND), P4.8 (GND), POT2.3 (B), POT3.3 (B), POT4.3 (B), POT5.3 (B), Q5.2 (E), Q6.2 (E), R1.2, R2.2, R16.2, R17.2, R21.1, SW1.C, SW1.D (1), SW2.P$3 (3), SW2.P$4 (4), SW3.P$3 (3), SW3.P$4 (4), U1.1 (C)
IO0: IC5.P$25, IC9.12, Q3.3 (C)
IO2: IC5.P$24, P1.P$7, Q4.3 (C), R23.1
IO4: IC4.22 (CSB), IC5.P$26
IO5: IC5.P$29, P3.CS, P3.CS1
IO12: IC4.24 (SCLK), IC5.P$14, IC9.13
IO13: IC4.23 (SDIN), IC5.P$16, IC9.11
IO14: IC5.P$13, P1.P$5, R22.1
IO15: IC5.P$23, P1.P$3, R20.1
IO18: IC5.P$30, P3.SCK, P3.SCK1
IO19: IC5.P$31, SJ1.2
IO21: IC4.3 (BCLK), IC5.P$33
IO22: IC4.4 (DACDAT), IC5.P$36
IO23: IC5.P$37, P3.SDI/MOSI, P3.SDI/MOSI1
IO25: IC4.5 (DACLRC), IC4.7 (ADCLRC), IC5.P$10
IO26: IC5.P$11, P3.DC/RS, P3.DC/RS1
IO27: IC4.6 (ADCDAT), IC5.P$12
IO32: IC5.P$8, IC9.10
IO33: C35.1, IC5.P$9, R29.1, SW1.B
IO34: C37.1, IC5.P$6, R31.1, SW1.E (2)
IO35: C33.1, IC5.P$7, R28.1, SW1.A
LHPOUT: IC4.9 (LHPOUT)
LIN: C13.1, IC4.20 (LLINEIN)
LOUT: C3.2, IC4.12 (LOUT)
MICBIAS: IC4.17 (MICBIAS)
MICIN: IC4.18 (MICIN)
unnamed: IC6.P$9, R24.2
unnamed: IC6.P$8, R19.1, R21.2
unnamed: Q2.1 (B), R25.1
unnamed: P2.P1, R19.2
unnamed: P1.P$2, R18.1
unnamed: Q3.1 (B), R26.1
unnamed: P3.SDD/MISO, P3.SDD/MISO1, SJ1.1
unnamed: J5.IN, R34.2
unnamed: Q4.1 (B), R27.1
unnamed: J6.IN, R35.2
unnamed: Q5.1 (B), R34.1
unnamed: Q6.1 (B), R35.1
unnamed: J7.IN, R39.1
unnamed: J11.IN, R51.1
unnamed: C53.1, IC10.9, R50.2, R51.2, R58.1
unnamed: J8.IN, R41.1
unnamed: C49.1, IC10.2, R38.2, R39.2, R46.1
unnamed: POT3.2 (W), R44.1
unnamed: C50.1, IC10.6, R40.2, R41.2, R47.1
unnamed: J12.IN, R53.1
unnamed: C54.1, IC10.13, R52.2, R53.2, R59.1
unnamed: POT2.2 (W), R42.1
unnamed: J9.IN, R43.1
unnamed: C51.1, IC11.2, R42.2, R43.2, R48.1
unnamed: J13.IN, R55.1
unnamed: C55.1, IC11.13, R54.2, R55.2, R60.1
unnamed: J10.IN, R45.1
unnamed: C52.1, IC11.6, R44.2, R45.2, R49.1
unnamed: J14.IN, R57.1
unnamed: C56.1, IC11.9, R56.2, R57.2, R61.1
unnamed: J1.IN, R4.2
unnamed: IC2.2, R4.1, R8.2
unnamed: D1.+, P4.9 (+12V), P4.10 (+12V)
unnamed: POT1.R1_1 (A), R8.1
unnamed: POT5.2 (W), R56.1
unnamed: IC2.1, POT1.R1_2 (W), POT1.R1_3 (B), R14.2
unnamed: C9.2, C12.2, R14.1, R16.1
unnamed: POT4.2 (W), R54.1
unnamed: J2.IN, R5.2
unnamed: IC2.6, R5.1, R9.2
unnamed: POT1.R2_1 (A), R9.1
unnamed: IC2.7, POT1.R2_2 (W), POT1.R2_3 (B), R15.2
unnamed: C5.2, IC4.26 (XTO), Q1.2
unnamed: C4.2, IC4.25 (XTI/MCLK), Q1.1
unnamed: C10.2, C13.2, R15.1, R17.1
unnamed: C7.1, IC3.1, R10.2, R12.1
unnamed: D1.-, F1.2
unnamed: C7.2, IC3.2, R6.2, R10.1
unnamed: C2.1, R1.1, R6.1
unnamed: C36.+, IC8.1 (VI), R30.1
unnamed: J3.IN, R12.2
unnamed: D2.-, P4.1 (-12V), P4.2 (-12V)
unnamed: C8.1, IC3.7, R11.2, R13.1
unnamed: C8.2, IC3.6, R7.2, R11.1
unnamed: C11.1, C14.1, IC4.16 (VMID)
unnamed: C3.1, R2.1, R7.1
unnamed: J4.IN, R13.2
unnamed: D2.+, F2.2
unnamed: L1.A, R32.1
RHPOUT: IC4.10 (RHPOUT)
RIN: C12.1, IC4.19 (RLINEIN)
ROUT: C2.2, IC4.13 (ROUT)
RTS: IC6.P$19, Q2.2 (E), R26.2, R27.2
RXD: IC5.P$34, IC6.P$21
TXD: IC5.P$35, IC6.P$20
VN_IO39: C47.1, IC5.P$5, Q5.3 (C), R36.2, SW2.P$1 (1), SW2.P$2 (2)
VP_IO36: C48.1, IC5.P$4, Q6.3 (C), R37.2, SW3.P$1 (1), SW3.P$2 (2)

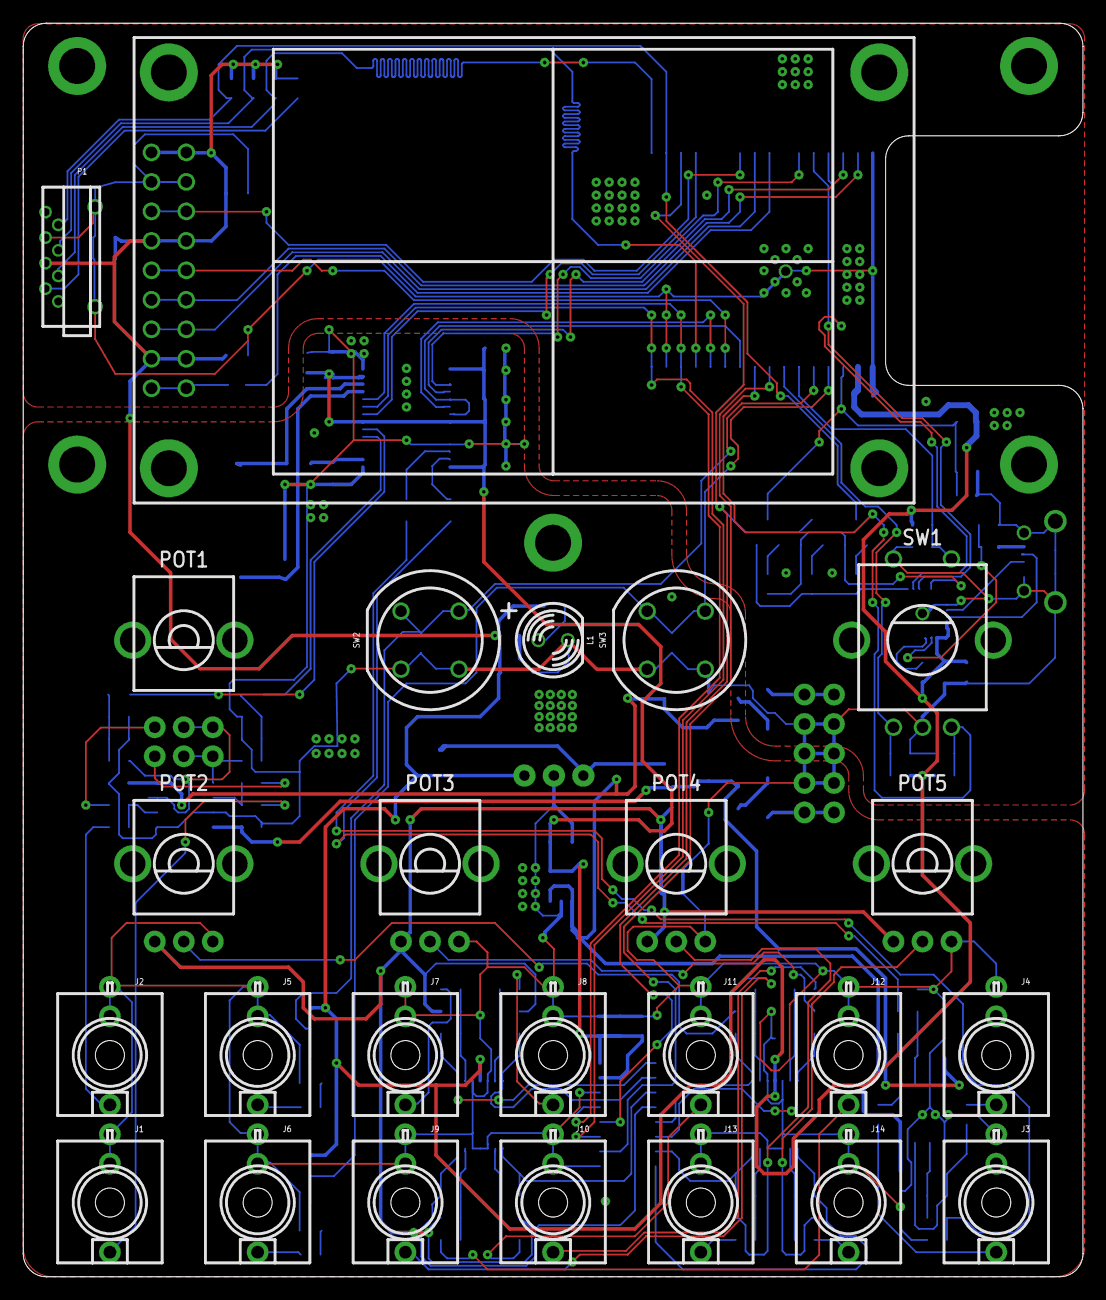
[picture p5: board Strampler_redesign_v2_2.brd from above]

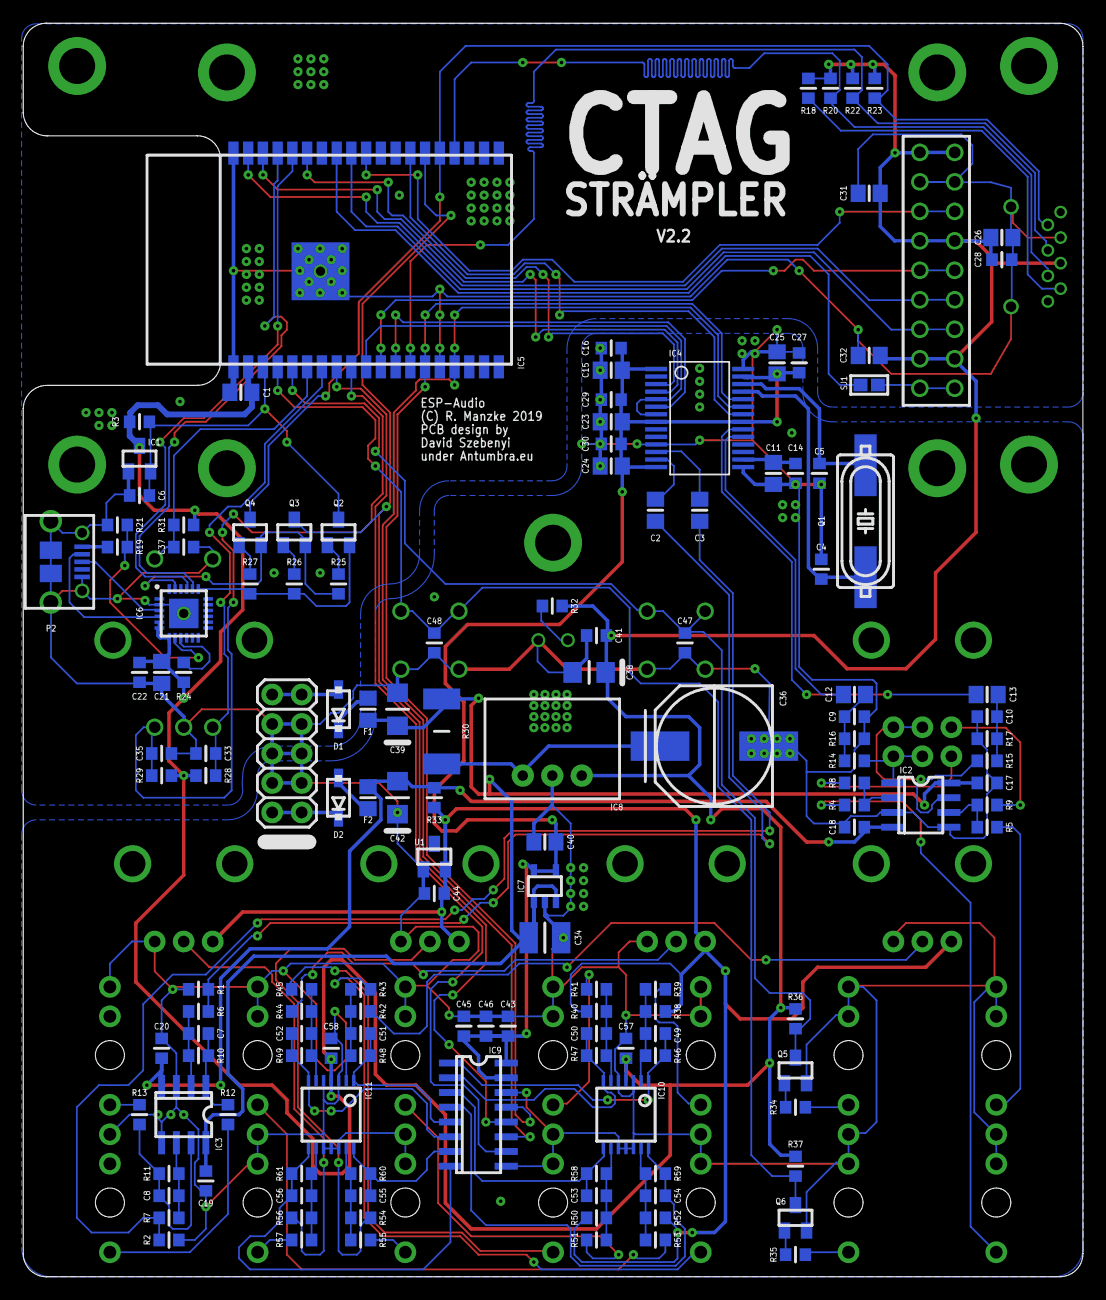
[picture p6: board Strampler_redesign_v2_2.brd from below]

Board: 2 copper layers, 91.3 x 108.0 mm, 174 parts (144 on the bottom side), 106 nets.

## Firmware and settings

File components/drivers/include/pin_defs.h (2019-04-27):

#pragma once


// pin definitions from ESP WROVER module
// TFT SPI
#define SPI_TFT_CS_PIN 5
#define SPI_TFT_DC_PIN 26
#define SPI_TFT_MOSI_PIN 23
#define SPI_TFT_SCK_PIN 18
#define SPI_TFT_MISO_PIN 19 // could be used as free output pin e.g. for debugging purposes

// ADC + CODEC
#define SPI_ADC_CS_PIN 32
#define SPI_CODEC_CS_PIN 4
#define SPI_ADC_MISO_PIN 0
#define SPI_ADCCODEC_MOSI_PIN 13
#define SPI_ADCCODEC_SCK_PIN 12
#define I2S_BCLK_PIN 21
#define I2S_LRCLK_PIN 25
#define I2S_ADCDAT_PIN 27
#define I2S_DACDAT_PIN 22

// Trigger inputs
#define TRIG0_PIN 39
#define TRIG1_PIN 36

// UI Encoder
#define ENC_BTN_PIN 34
#ifndef CONFIG_SWAP_ENCODER_PINS
    #define ENC_A_PIN 33
    #define ENC_B_PIN 35
#else 
    #define ENC_A_PIN 35
    #define ENC_B_PIN 33
#endif

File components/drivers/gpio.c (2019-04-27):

#include "freertos/FreeRTOS.h"
#include "freertos/task.h"
#include "freertos/queue.h"
#include "driver/gpio.h"
#include <time.h>
#include <sys/time.h>
#include "gpio.h"
#include "pin_defs.h"
#include "ui_events.h"
#include "audio_events.h"

#define ESP_INTR_FLAG_DEFAULT 0

static xQueueHandle ui_event_queue = NULL;

static void IRAM_ATTR gpio_isr_handler_encoder1(void* arg)
{
    ui_ev_ts_t ev;
    uint32_t pin = (uint32_t) arg;
    uint32_t pv = (uint32_t) gpio_get_level(pin);
    uint32_t a = gpio_get_level(ENC_A_PIN);
    uint32_t b = gpio_get_level(ENC_B_PIN);
    static uint32_t check = 0;
    // de bounce
    if(pv) return;
    if(pin == ENC_B_PIN && a){
        check = ENC_B_PIN;
        return;
    }
    if(pin == ENC_A_PIN && b){
        check = ENC_A_PIN;
        return;
    }
    // real event
    if(check == ENC_A_PIN && !a && !b){
        ev.event = EV_ENC1_BWD;
        xQueueSendFromISR(ui_event_queue, &ev, NULL);
    }
    if(check == ENC_B_PIN && !a && !b){
        ev.event = EV_ENC1_FWD;
        xQueueSendFromISR(ui_event_queue, &ev, NULL);
    }
    check = 0;
    return;
}

static void IRAM_ATTR gpio_isr_handler_encoder1_btn1(void* arg)
{
    ui_ev_ts_t ev;
    static ui_ev_t state = EV_ENC1_BT_UP;
    uint32_t pv = gpio_get_level(ENC_BTN_PIN);
    // de-bounce
    if(pv == 0 && state == EV_ENC1_BT_DWN) return;
    if(pv == 1 && state == EV_ENC1_BT_UP) return;
    // real event
    if(pv == 1 && state == EV_ENC1_BT_DWN) ev.event = EV_ENC1_BT_UP;
    if(pv == 0 && state == EV_ENC1_BT_UP) ev.event = EV_ENC1_BT_DWN;
    state = ev.event;
    xQueueSendFromISR(ui_event_queue, &ev, NULL);
}

void initGPIO(xQueueHandle queueui){
    // set queues
    ui_event_queue = queueui;
    
    gpio_config_t io_conf;

    //interrupt of rising edge
    io_conf.intr_type = GPIO_PIN_INTR_NEGEDGE;
    //bit mask of the pins
    io_conf.pin_bit_mask = ((1ULL<<ENC_A_PIN) | (1ULL<<ENC_B_PIN) | (1ULL<<ENC_BTN_PIN));
    //set as input mode    
    io_conf.mode = GPIO_MODE_INPUT;
    //disable pull-down mode
    io_conf.pull_down_en = 0;
    //disable pull-up mode
    io_conf.pull_up_en = 0;
    gpio_config(&io_conf);

    //change gpio intrrupt type for one pin
    gpio_set_intr_type(ENC_BTN_PIN, GPIO_INTR_ANYEDGE);

    //install gpio isr service
    gpio_install_isr_service(ESP_INTR_FLAG_DEFAULT);
    //hook isr handler for encoder 1
    gpio_isr_handler_add(ENC_A_PIN, gpio_isr_handler_encoder1, (void*) ENC_A_PIN);
    gpio_isr_handler_add(ENC_B_PIN, gpio_isr_handler_encoder1, (void*) ENC_B_PIN);
    //hook isr handler for encoder 1 button
    gpio_isr_handler_add(ENC_BTN_PIN, gpio_isr_handler_encoder1_btn1, (void*) ENC_BTN_PIN);

    io_conf.intr_type = GPIO_PIN_INTR_DISABLE;
    //set as output mode
    io_conf.mode = GPIO_MODE_INPUT;
    io_conf.pin_bit_mask = ((1ULL<<TRIG0_PIN)| (1ULL<<TRIG1_PIN));
    //disable pull-down mode
    io_conf.pull_down_en = 0;
    //disable pull-up mode
    io_conf.pull_up_en = 0;
    //configure GPIO with the given settings
    gpio_config(&io_conf);

    /* debug pin
    io_conf.intr_type = GPIO_PIN_INTR_DISABLE;
    //set as output mode
    io_conf.mode = GPIO_MODE_OUTPUT;
    //bit mask of the pins that you want to set,e.g.GPIO18/19
    io_conf.pin_bit_mask = 1ULL<<SPI_TFT_MISO_PIN;
    //disable pull-down mode
    io_conf.pull_down_en = 0;
    //disable pull-up mode
    io_conf.pull_up_en = 0;
    //configure GPIO with the given settings
    gpio_config(&io_conf);
    */
}

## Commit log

2019-05-04 added config file validation at device start
2019-05-06 when swapping a sample sample start, loop start and loop end get updated correctly
    [audio.c]
2019-06-16 silence file for initial slot assignment implemented
2019-06-23 sample menu only enabled when connected to WiFi
2021-03-15 hardware added, Antumbra designs added
    [Strampler_redesign_v2_2.brd, Strampler_redesign_v2_2.sch, strampler_panel_v2_2.brd]
